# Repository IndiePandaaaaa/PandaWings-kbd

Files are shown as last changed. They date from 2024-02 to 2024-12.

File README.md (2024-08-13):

# PandaWings Keyboard

The PandaWings is a split keyboard with 3x5 column staggered keys with two 
additional keys on each side and with 3 thumb keys, based on 
[crkbd v3](https://github.com/foostan/crkbd/tree/v3-final).
Crkbd stands for Corne Keyboard.

## Idea

I wanted to create a corne compatible with the seeed xiao controller
instead of the pro-micro controllers. Due to missing pins for the matrix, 
the matrix is wired in a 4x5 grid and reshaped for thumb keys and two additional 
side keys. LEDs are permanent, toggleable with hardware switch. Per-key-RGB 
or display can be chosen while building.

## Lineup

- PandaWings v1 - Cherry MX switches: <br>
  Hotswappable Cherry MX switches, with LEDs, optional per-key-RGB or displays
- [PLANNED] PandaWings v2 - Cherry MX and Chocolate switches: <br>
  Hotswappable Cherry MX and Chocolate switches

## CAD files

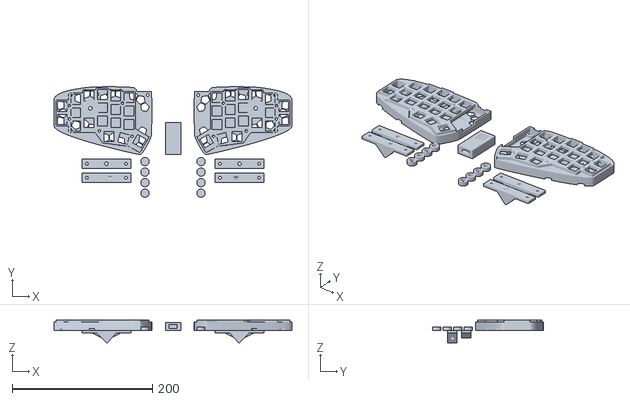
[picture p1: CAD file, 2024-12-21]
case/stl/PandaWings_case_full_set.stl
339.8 x 157.9 x 32.2

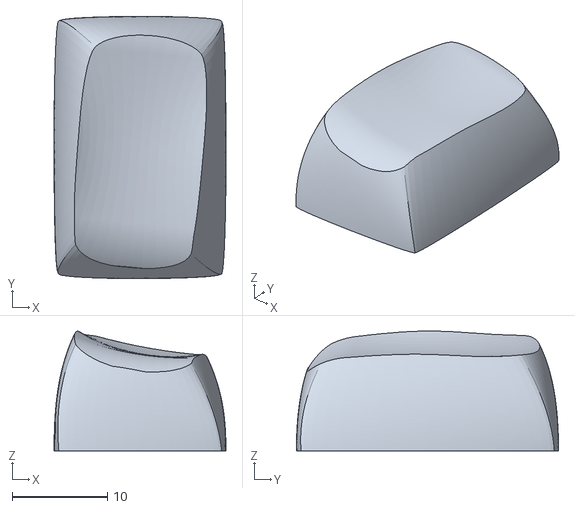
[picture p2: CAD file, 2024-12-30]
keycaps/stl/PandaWings-keycaps-thumbs-r1.stl
18.1 x 27.6 x 12.6

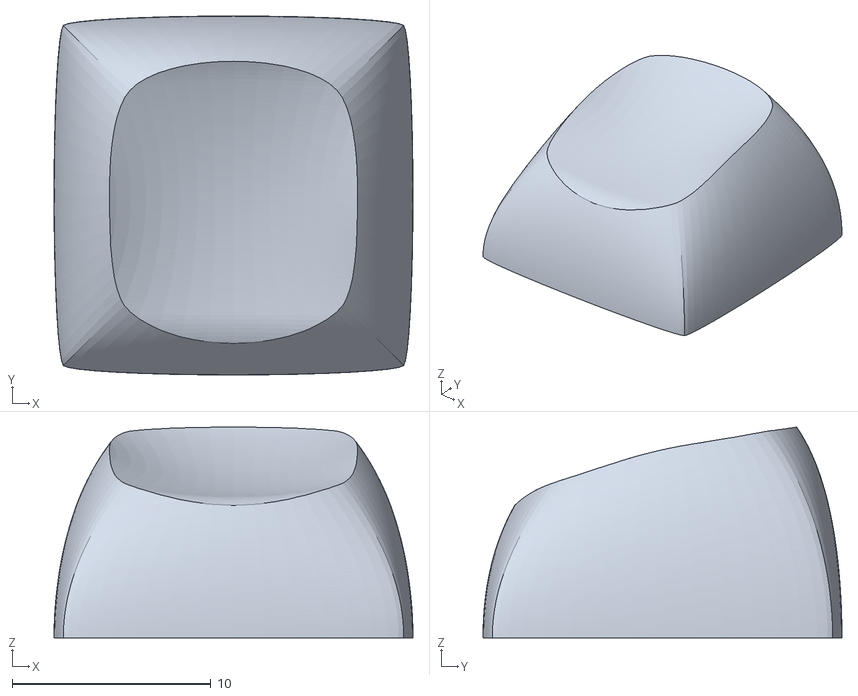
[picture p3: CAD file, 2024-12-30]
keycaps/stl/PandaWings-keycaps-alphanum-2-12x.stl
18.1 x 18.1 x 10.6

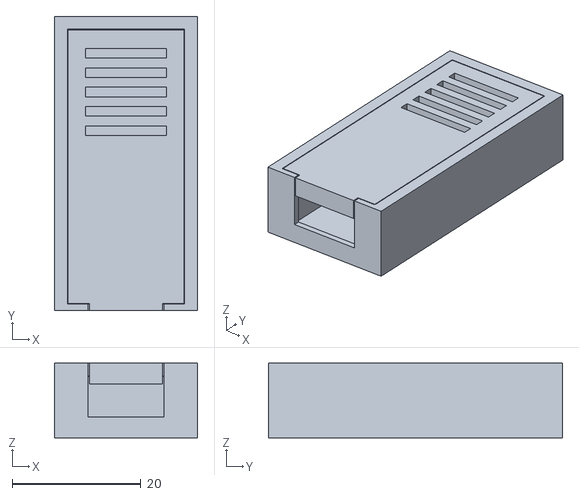
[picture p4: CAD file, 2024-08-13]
case/stl/PandaWings_dongle_case.stl
22.2 x 45.7 x 11.6

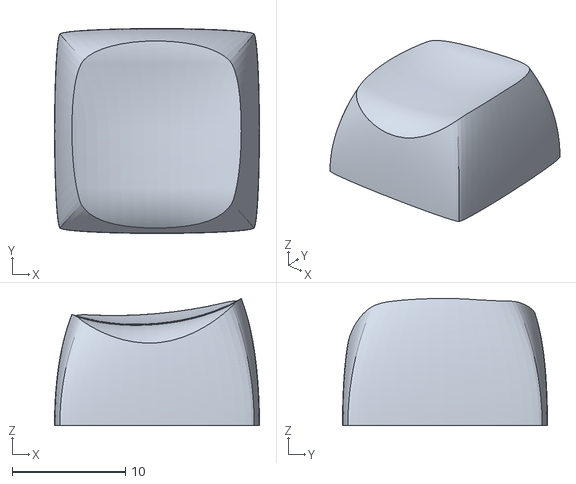
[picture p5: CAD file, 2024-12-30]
keycaps/stl/PandaWings-keycaps-thumbs-r2.stl
18.1 x 18.1 x 11.2

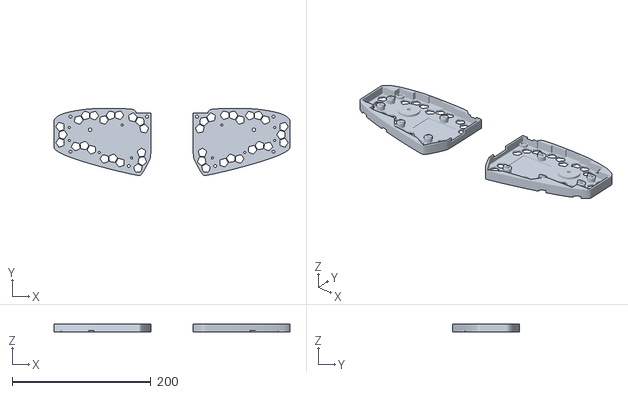
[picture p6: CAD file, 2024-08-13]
case/stl/PandaWings_case_M3.stl
339.8 x 96.8 x 11.9

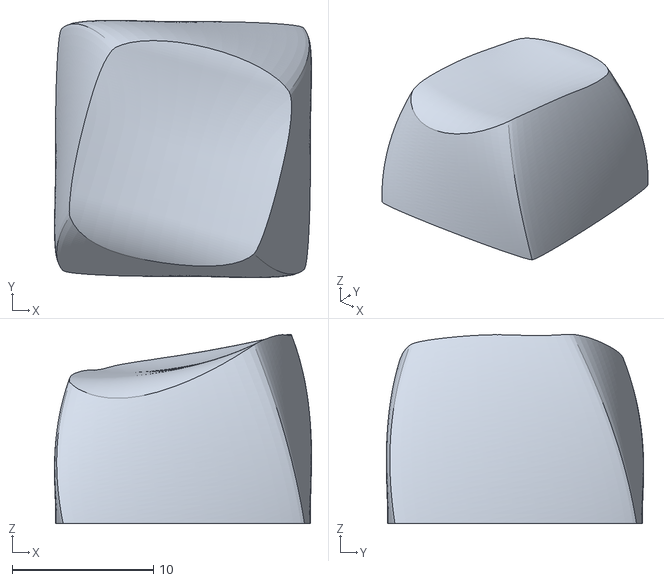
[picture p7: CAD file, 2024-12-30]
keycaps/stl/PandaWings-keycaps-thumbs-r3.stl
18.2 x 18.2 x 13.4

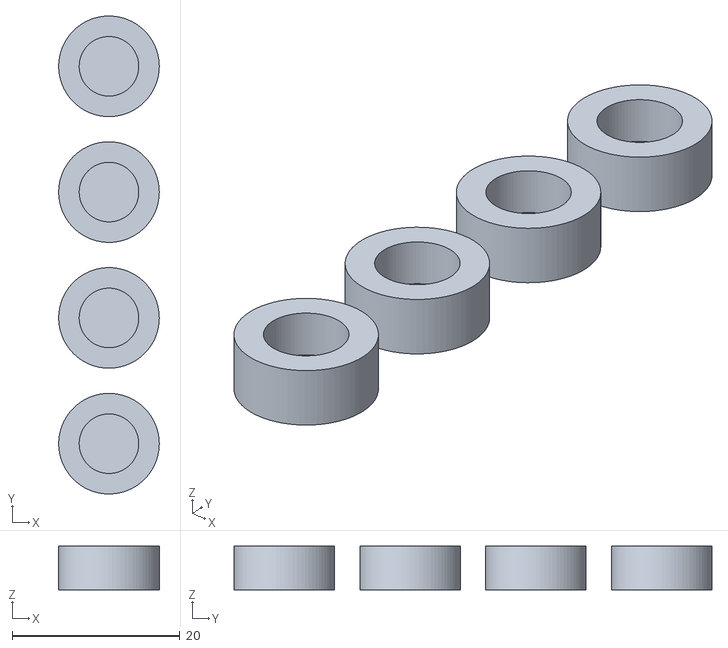
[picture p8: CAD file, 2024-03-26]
case/stl/PandaWings_tenting_caps_M4.stl
12.0 x 57.0 x 5.22

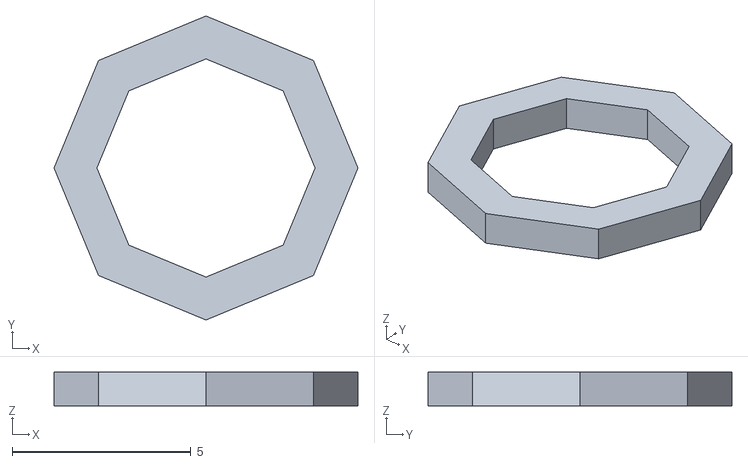
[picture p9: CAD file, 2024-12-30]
keycaps/stl/PandaWings-travelstop-gloriouspanda-gloriousa40thin.stl
8.50 x 8.50 x 0.95

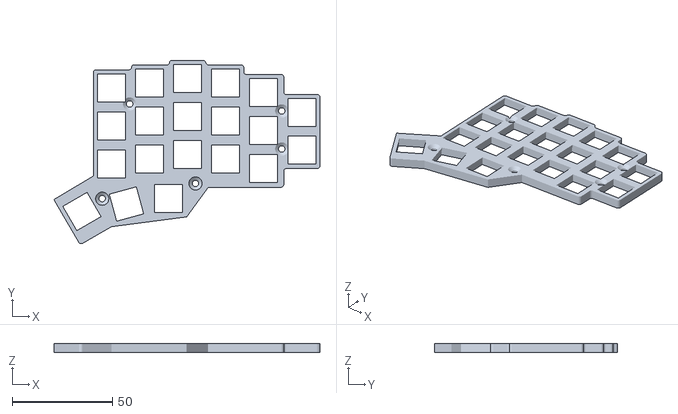
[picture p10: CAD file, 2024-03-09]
case/stl/PandaWings_switch_plate_M3.stl
132.9 x 91.6 x 4.70

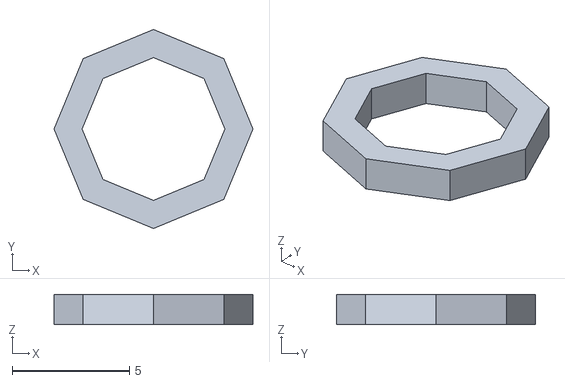
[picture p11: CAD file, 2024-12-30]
keycaps/stl/PandaWings-travelstop-cherrymxred-ring009.stl
8.50 x 8.50 x 1.30

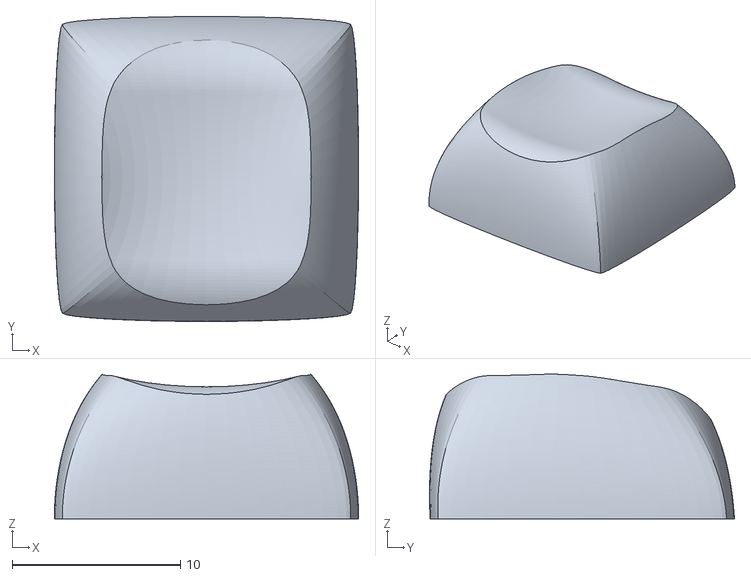
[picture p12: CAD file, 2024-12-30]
keycaps/stl/PandaWings-keycaps-alphanum-1-12x.stl
18.1 x 18.1 x 8.59

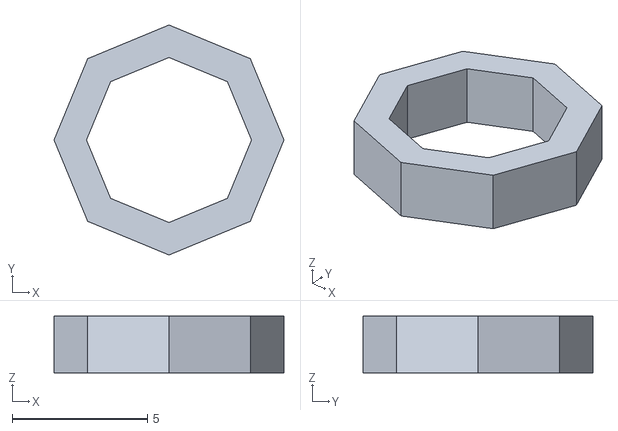
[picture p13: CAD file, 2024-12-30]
keycaps/stl/PandaWings-travelstop-cherrymxsilver-ring009.stl
8.50 x 8.50 x 2.10

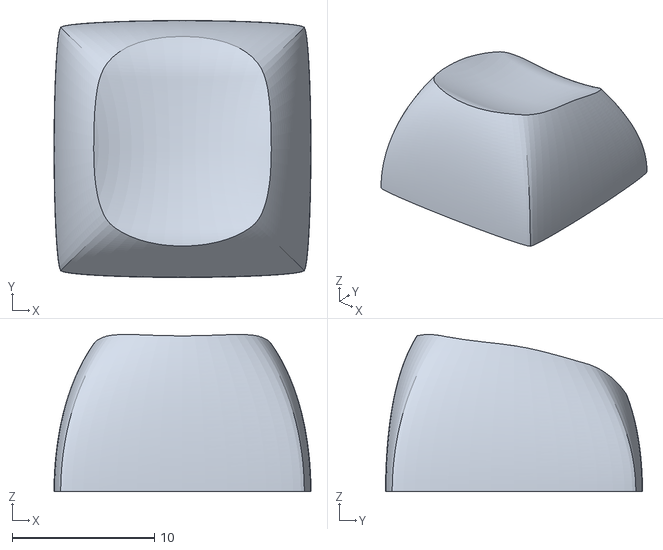
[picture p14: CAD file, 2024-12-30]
keycaps/stl/PandaWings-keycaps-alphanum-0-10x.stl
18.1 x 18.1 x 11.0

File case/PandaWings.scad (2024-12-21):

// created by IndiePandaaaaa

TOLERANCE = .15;
THICKNESS = 2.5;
$fn = 75;


// DONGLE
DONGLE_CASE = true;

// CASE
KEYBOARD_CASE = true;
SWITCH_PLATE = true;

// CASE ADDONS
WRIST_REST = false;
LAPTOP_STANDOFFS = false;
TENTING_CAPS = true;
TENTING_SOCKET = true;


BATTERY_SIZE = [41.2, 29.5, 4.8];  // Battery 600mAh (Jauch LP503040JH)

PCB_SIZE = [133.8, 92.6];

module nut_cutout(standard = "M3", thickness = 0, tolerance = .1) {

  nut_m3 = [6.1, 2.4];
  nut_m4 = [7.7, 3.2];
  
  rotate([0, 0, 30])
    if (standard == "M3" || standard == "m3" || standard == "3" || standard == 3)
      cylinder(d = nut_m3[0] + tolerance, h = nut_m3[1] > thickness ? nut_m3[1] + tolerance : thickness, $fn = 6);
    else if (standard == "M4" || standard == "m4" || standard == "4" || standard == "4")
      cylinder(d = nut_m4[0] + tolerance, h = nut_m4[1] > thickness ? nut_m4[1] + tolerance : thickness, $fn = 6);
}

module mounting(thickness, diameter = 4.7, screws = false, countersunk = false, nuts = false, standoffs = false) {
  cone_height_m3 = 1.7;
  cone_height_m4 = 2.3;
  
  standoff_offset = 2.75;

  MOUNTING_HOLES = [
    [18.9, 26.3],
    [18.9, 45.3],
    [62.0, 62.5],
    [94.9, 22.8],
    [108.6, 70.1],
  ];

  translate([PCB_SIZE[0], PCB_SIZE[1], 0]) mirror([0, 1, 0]) mirror([1, 0, 0]) union() {
    for (i = MOUNTING_HOLES) {
      translate([i[0], i[1], 0]) {
        if (countersunk && !nuts && diameter >= 3 && diameter <= 3.5)
          translate([0, 0, thickness - cone_height_m3 - .5])
            cylinder(d1 = diameter, d2 = diameter * 2 + 0.4, h = cone_height_m3 + .5);
        else if (countersunk && !nuts && diameter >= 4 && diameter <= 4.5)
          translate([0, 0, thickness - cone_height_m4 - .5])
            cylinder(d1 = diameter, d2 = diameter * 2 + 0.4, h = cone_height_m4 + .5); 
        else if (!countersunk && nuts && diameter == 3)
          nut_cutout("M3", thickness);
        else if (!countersunk && nuts && diameter == 4)
          nut_cutout("M4", thickness);
      }

      if (screws && !nuts) translate([i[0], i[1], 0]) cylinder(d = diameter, h = thickness);

      if (standoffs) translate([i[0] + standoff_offset, i[1], 0]) cylinder(d = diameter, h = thickness);
    }
  }
}

module dongle_case(thickness = 2, tolerance = .2) {
  adapter_width = 14.5; // Adafruit P5329
  adapter_length = 14.5;
  adapter_height = 7.2;
  
  controller_width = 17.8; // Seeed XIAO BLE
  controller_length = 21.0;

  connector_wall_thickness = 1;
  connector_offset = 1.2;
  connector_width = 11.4;
 
  distance_length = 4.4;
  distance_width = 10;

  top_tolerance = .1;

  total_length = connector_wall_thickness + adapter_length + distance_length + controller_length + thickness * 2 + tolerance * 4;
  total_width = (thickness + tolerance) * 2 + controller_width;
  total_height = (thickness + tolerance) * 2 + adapter_height;

  inner_height = total_height - thickness - top_tolerance;
  connector_wall_width = (total_width - connector_width) / 2 - tolerance;
  adapter_wall_width = (total_width - adapter_width) / 2 - tolerance;
  
  union() {
    // bottom
    cube([total_width, total_length, thickness]);
    cube([total_width, connector_wall_thickness, thickness + connector_offset]); 
    translate([0, total_length - controller_length, 0]) cube([total_width, controller_width, thickness + connector_offset]);

    // walls
    cube([thickness, total_length, total_height]);
    translate([total_width - thickness, 0, 0]) cube([thickness, total_length, total_height]);
    translate([0, total_length - thickness, 0]) cube([total_width, thickness, total_height]);
    translate([0, total_length - thickness * 2, 0]) cube([total_width, thickness, inner_height]);
    cube([adapter_wall_width, connector_wall_thickness + adapter_length, inner_height]);
    translate([total_width - adapter_wall_width, 0, 0])
      cube([adapter_wall_width, connector_wall_thickness + adapter_length, inner_height]); 
    cube([connector_wall_width, connector_wall_thickness, total_height]);
    translate([total_width - connector_wall_width, 0, 0])
      cube([adapter_wall_width, connector_wall_thickness, total_height]);
  }

  difference() {
    union() {
      top_length = total_length - thickness - connector_wall_thickness - top_tolerance * 2;
      translate([thickness + top_tolerance, connector_wall_thickness + top_tolerance, total_height - thickness])
        cube([controller_width + (tolerance - top_tolerance) * 2, top_length, thickness]);
      translate([connector_wall_width + tolerance, 0, total_height - thickness - connector_offset]) {
        cube([connector_width, connector_wall_thickness, thickness + connector_offset]);
        translate([0, 0, connector_offset]) cube([connector_width, thickness, thickness]);
      }
    }

    cooling_width = 12.5;
    cooling_y = 27.2;
    for (i = [0:4]) {
      translate([(total_width - cooling_width) / 2, cooling_y + 3 * i, total_height - thickness - tolerance])
        cube([cooling_width, 1.5, thickness + tolerance * 2]);
    }
  }
}

module switch_plate(thickness = 2.5) {
  max_thickness = 4.7;
  mx_plate_thickness = 1.5;

  translate([3, 3.2, 10]) difference() {
    linear_extrude(max_thickness)
      import("./svg/PandaWings_contour_half_switch_plate.svg", dpi = 300);
    translate([0, 0, -.1]) linear_extrude(max_thickness - mx_plate_thickness + .1)
      import("./svg/PandaWings_contour_half_switch_plate_outer_cutout.svg", dpi = 300);
    translate([0, 0, max_thickness - mx_plate_thickness - .1]) linear_extrude(mx_plate_thickness + .2)
      import("./svg/PandaWings_contour_half_switch_plate_inner_cutout.svg", dpi = 300);
    translate([0, 0, -.1]) mounting(max_thickness + .2, 3.2, screws = true, countersunk = true); // 3.2 mm for M3
  }
}

module wrist_rest_mounting(thickness, case_height, cutout = false) {
  translate([82, 10, 0]) {
    wr_loc = [ [0, 0], [40, 9.5] ];
    size = [9, 20, thickness + .2];

    for (i = wr_loc) {
      translate([i[0], i[1], -.1]) union () {
        cube([size[0], size[1] - size[0] / 2, size[2]]);
        translate([size[0] / 2, size[1] - size[0] / 2, 0]) {
          cylinder(d = size[0], h = size[2]);
          cylinder(d = 2.95, h = case_height - 1.5);
        }
      }
    }
  }
}

module keyboard_case(wrist_rest = true, thickness = 2.5, min_thickness = 1.5, pcb_thickness = 1.6) {
  // heights
  battery_connector_height = 5;
  above_pcb = 3;
  below_pcb = min_thickness + BATTERY_SIZE[2] + 1;
  case_height = below_pcb + pcb_thickness + above_pcb;

  mounting_offset = [2.95, 3.2];
  // todo: find height issue, below_pcb != underside of pcb
  
  tenting_locations = [
    [6, 85], 
    [32, 14],
    [116.25, 34.5],
    [116.25, 85],
  ];

  tenting_socket_pos = [88, 66, 5.2];

  difference() {
    union() {
      difference() {
        linear_extrude(case_height)
          import("./svg/PandaWings_contour_case.svg", dpi = 300); 
        translate([0, 0, thickness]) linear_extrude(case_height - thickness + .1)
          import("./svg/PandaWings_contour_half_pcb.svg", dpi = 300);
        translate([0, 0, -.1]) linear_extrude(thickness + .2)
          import("./svg/PandaWings_contour_case_cutout.svg", dpi = 300);
        translate([mounting_offset[0], mounting_offset[1], -.1]) mounting(thickness + .2, 3, nuts = true);
      }
      translate([tenting_socket_pos[0], tenting_socket_pos[1], 0]) cylinder(d = 26, h = tenting_socket_pos[2]);
      difference() {
        translate([mounting_offset[0], mounting_offset[1], thickness]) union() {
          mounting(below_pcb, 4.5, screws = true);
          mounting(below_pcb - 2, 10, screws = true);
        }
      }


      translate([mounting_offset[0], mounting_offset[1], thickness]) 
        mounting(below_pcb, diameter = 4.5, standoffs = true);
      
      for (i = tenting_locations) {
        translate([i[0], i[1], thickness -.1]) {
          difference() {
            cylinder(d = 10, h = 3);
            nut_cutout("M4", 3);
          } 
        }
      }
    }

    for (i = tenting_locations) translate([i[0], i[1], -.1]) cylinder(d = 4.2, h = below_pcb + .1);
    translate([mounting_offset[0], mounting_offset[1], thickness - .1]) 
      mounting(below_pcb + .2, 3.2, screws = true);

    // battery
    translate([20, 38, min_thickness + .15]) cube(BATTERY_SIZE);

    // USB port
    translate([7.5, 88, below_pcb + 2.5]) cube([9, 5, 8]);

    // side switches
    translate([0, 34, below_pcb]) cube([5, 24, 55]);

    // wrist rest mounting
    wrist_rest_mounting(thickness, case_height, cutout = false);

    // tenting socket
    translate([tenting_socket_pos[0], tenting_socket_pos[1], -.1]) cylinder(d = 5.1, h = tenting_socket_pos[2] + .2); // UNC 1/4" threading
  }

}
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

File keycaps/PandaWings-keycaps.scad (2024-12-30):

// created by IndiePandaaaaa

use <des/MX_DES_Thumb.scad>
use <des/MX_DES_Standard.scad>
use <des/MX_DES_travel_stop.scad>

RENDER_ALL_CAPS = false;

// cherry activation point
CSILVER = 1.2;  // cherry mx silver
CRED = 2;  // cherry mx red
GPANDA = 2.5;  // glorious panda

// o-ring uncompressed thickness
RING_009 = 1.8;
GLORIOUS_A40_THIN = 1.5;

// needed keys
standard = [ [0, 10], [1, 12], [2, 12] ];
thumbs = [ [0, 1], [1, 1], [2, 1] ];
keycount = 6 + standard[0][1] + standard[1][1] + standard[2][1];


module standard_caps(id) {
  keycap_standard(
    keyID = id, // change profile refer to KeyParameters Struct
    cutLen = 0, // Don't change. for chopped caps
    Stem = true, // turn on shell and stems
    Dish = true, // turn on dish cut
    Stab = 0,
    visualizeDish = false, // turn on debug visual of Dish
    crossSection = false, // center cut to check internal
    homeDot = false, // turn on homedots
    Legends = false  // not working
  );
}

module thumb_caps(id) {
  keycap_thumb(
    keyID = id, //change profile refer to KeyParameters Struct
    cutLen = 0, //Don't change. for chopped caps
    Stem = true, //tusn on shell and stems
    Dish = true, //turn on dish cut
    Stab = 0,
    visualizeDish = false, // turn on debug visual of Dish
    crossSection = false, // center cut to check internal
    homeDot = false, //turn on homedots
    Legends = false // not working
  );
}

union() {
  // alphanumerical keycaps
  translate([10, 30, 0]) for (i = [0:len(standard) - 1]) {
    for (j = [0:(RENDER_ALL_CAPS ? standard[i][1]:0)]) {
      translate([RENDER_ALL_CAPS ? 20 * j - (20 * standard[i][1]) / 2 : 0, 20 * i, 0]) standard_caps(id = standard[i][0]);
    }
  }
  
  // thumb cluster keycaps
  translate([10, 0, 0]) for (i = [0:1]) {
    mirror([i, 0, 0]) translate([20 * i, 0, 0]) for (x = [0:len(thumbs) - 1]) {
      translate([20 * x, 0, 0]) thumb_caps(id = thumbs[x][0]);
    }
  }

  // travel_stop
  translate([10, -30, 0]) for (i=[0: (RENDER_ALL_CAPS? keycount-1:0)]) {
    translate([15*(i%5), -15*floor(i/5), 0]) travel_stop(GPANDA, GLORIOUS_A40_THIN);
  }
}

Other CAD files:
keycaps/stl/PandaWings-keycaps-thumbs-l2.stl
keycaps/stl/PandaWings-keycaps-thumbs-l1.stl
keycaps/stl/PandaWings-keycaps-thumbs-l3.stl
case/stl/PandaWings_tenting_mounting_wood_screws.stl

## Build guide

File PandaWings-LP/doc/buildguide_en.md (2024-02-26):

# Build Guide

This is the build guide for Corne Chocolate.
[Click here for the Corne Cherry build guide](
https://github.com/foostan/crkbd/blob/master/corne-cherry/doc/buildguide_en.md).

## Parts

### Required

| Name | Count | Remarks |
|:-|:-|:-|
| PCB | 2 pieces | |
| Top plate | 2 pieces | |
| Bottom plate | Two pieces | PCB type and acrylic type are available |
| Pro Micro protection plate | 2 pieces | |
| Pro Micro | 2 | |
| TRRS Jack | 2 | |
| Tactile switch | 2 pieces | |
| Diode | 42 pieces | Compatible with chip components only
| Kailh PCB Socket (for Choc) | 42 | |
| Key switch | 42 pieces | Compatible with Choc (low profile) only |
| Key-caps | 42 | 1u 40, 1.5u 2 |
| OLED module | 2 pieces | |
| 4 pin headers | 2 | |
| 4 pin sockets | 2 | |
| Spacer M2 4.5mm | 10 | |
| Spacer M2 9mm | Four | |
| Screw M2 4mm | 28 | |
| Cushion rubber | 8 pieces | |
| TRS (3 pole) cable | 1 | TRRS (4 pole) cable also available |
| Micro USB Cable | 1 | |

### Optional

| Name | Count | Remarks |
|:-|:-|:-|
| SK6812MINI | 54 | 42 for backlight, 12 for under-glow |

## Advance preparation

If you build the firmware yourself,
it will take some time to set up the environment,
so it's best to start at the beginning. \
For more information,
please see <https://github.com/foostan/crkbd/blob/master/doc/firmware_en.md>.

## Building

Since the PCB is reversible,
you first have to decide which one to use for the left side.



### Diodes

Solder the diodes to the PCB.

On Corne Cherry, it is up to you to choose which side to attach,
but with Corne Chocolate you must **be sure to attach it to the back**.
Mounting on the front will interfere with the top plate.

Since the diodes are very small,
it is easier to work with tweezers and inverted tweezers.
Since the **mounting orientation of the diode is crucial**,
it is possible to proceed smoothly
if you arrange the columns and rows to be mounted in advance,
as shown in the following photo.



The orientation of the diode is as follows.
Attach the chip component so that the "|||" mark on the diode is facing the "|"
of the diode mark "|◁" on the PCB (image from Corne Cherry).



Tip for soldering on SMD parts:
First put solder only on the right side of the pad.



Next, solder one of the diodes by melting the solder you already put on the board.
At this time,
it is recommended to use [reverse-action tweezers](https://www.alimed.com/_resources/cache/images/product/70895A_850x480-pad.jpg),
so that you can hold the SMD part firmly without applying force,
and concentrate on alignment and soldering instead.
Also, if the soldering iron is too hot or the solder is touched too long,
the flux contained in the solder may evaporate and form an undesirable pile solder,
but since it can be repaired later,
so at this point you should only care about attaching parts.
It's okay.



Then solder the other pin.
Be careful not to apply too much solder,
as a small amount is sufficient.
If you have applied too much,
you can remove it with a suction pump, blotting wire
or by scooping it with a soldering iron.



If the amount of solder on the pre-soldering side is too small,
add more soldering,
and if it is pilled up,
apply flux from above and heat to clean.



### TRRS jack, reset switch, pin socket



Solder the TRRS jack, reset switch and pin socket to the **front of the PCB**
as shown in the picture below.
Since the diode is attached on the back side,
it will be on the opposite side.



### Jumpers for OLED modules

When using an OLED module, use solder as jumpers (4 times per side) as follows.
**Please jumper only on the surface**.



If the jumper doesn't work,
you probably have a small amount of solder,
or the flux has vaporized.
If so, you can fix the jumper by applying more solder or separate flux.

### Pro Micro



Solder the pin headers to the white frame
and solder the Pro Micro with back side up.




When using the spring-loaded pin headers,
please refer to the [Helix Build Guide](
https://github.com/MakotoKurauchi/helix/blob/master/Doc/buildguide_en.md#pro-micro).

### OLED module



Insert the pin header into the OLED pin socket first,
then solder the pin header and the OLED module.
At this time,
make sure that the OLED module sits tightly on the socket
while holding it down with your finger,
because it tends to stick out easily.




### Operation check

We recommend that you check the operation at the stage
where the Pro Micro and OLED modules are attached
(it is difficult to isolate the problem at the end).

Before checking the correct operation,
flash the crkbd firmware to the Pro Micro
by referring to the [Firmware](#firmware) section below
(be sure to insert it on both sides).

Operation confirmation is performed
by connecting the left hand side to a PC with Micro USB
and connecting the left hand side and the right hand side with a TRS cable.
Since there may be a defect such as a jack,
make sure to connect the left and right
instead of one by one before checking the operation.
If you have done this correctly,
short-circuit the pad to attach the PCB socket with tweezers,
and the key pressed on the OLED module will be displayed.



## LED (optional)



I will install SK6812MINI.
The LED can be mounted even after completion,
so if you are worried about mounting it,
we recommend that you skip this chapter and complete it first.

SK6812MINI is very heat sensitive and breaks easily.
We recommend using a soldering iron with a temperature control function
and operating at a temperature of about 220°C to 270°C.
Even if the temperature is set that low,
the LED will be damaged if the iron is left on it for a long time,
so try to solder as quickly as possible.
Solder four LEDs at a time,
but we recommend soldering two at a time instead of four at a time
to prevent the LED temperature from rising,
as this will make it less likely to overheat.

First, check the mounting position.

Solder 1 - 6 so that the back side (under-glow) shines,
7 - 27 so that the front side (back-light) shines.
Below is the location to attach the LED (image from Corne Cherry).




For LEDs 1 to 6,
solder the part so that the black part circled below is on the bottom
and the silk mark indicated by the arrow is on the top.
Note that the direction changes between 1 - 3 and 4 - 5.



For 7 - 27,
perform soldering so that the largest pad surrounded by a circle
and the silk mark indicated by an arrow are adjacent to each other,
as shown below.



If everything was successfully soldered,
it will glow as follows.
If the LED lights only halfway,
the LEDs are connected in the order of the numbers.
Therefore, it is likely that the LED that does not emit light
or the previous LED are incorrectly soldered or damaged.





### Kailh PCB Socket



Apply solder to the pads on both sides on the back.
It is difficult to add it later,
so please fill it up beforehand.



Insert the socket and melt the solder.
At this time,
hold the socket with tweezers or your fingers so that the socket sticks to the board.



The soldering is now complete.




### Plate, switch



Use 4.5mm spacers for the top and bottom plates
and 9mm spacers for the OLED.



In addition,
it is recommended to paint the side of the plate with a black marker
because it looks better.



## Firmware

See below to flash the firmware to the ProMicro. \
<https://github.com/foostan/crkbd/blob/master/doc/firmware_en.md>

This is the end.



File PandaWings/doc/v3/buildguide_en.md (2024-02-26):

# Build Guide

This is the build guide for Corne Cherry v3.
[Click here for the Corne Cherry v2 build guide](
https://github.com/foostan/crkbd/blob/master/corne-cherry/doc/v2/buildguide_en.md).

## Parts

### Required

| Name | Count | Remarks |
|:-|:-|:-|
| PCB | 1 set | |
| Top plate | 2 sheets | 1.5mm-3mm thick |
| Bottom plate | 2 sheets | |
| OLED cover | 2 sheets | |
| ProMicro | 2 | Alternative: [Elite-C](https://deskthority.net/wiki/Elite-C) |
| TRRS jack | 2 | |
| Reset switch | 2 | |
| Diodes | 42 | SMD Only (SOD-123 Package) |
| PCB sockets | 42 | Compatible with Kailh and Gateron |
| Key switches | 42 | Only compatible with MX style |
| Keycaps | 42 pieces | 1u 40 pcs, 1.5u 2 pcs |
| Spacer M2 7.5mm | 10 pieces | For Case assembly |
| Spacer M2 9mm | 4 pieces | For OLED cover |
| Screw M2 4mm | 28 screws | |
| Rubber feet | 8 pieces | |
| TRRS (4 poles) cable | 1 | TRS (3 poles) cable is also compatible |
| Micro USB cable | 1 | Avoid charge-only cables |

### Optional

| Name | Count | Remarks |
|:-|:-|:-|
| OLED module | 2 | |
| SK6812MINI-E | 42 | LEDs for Backlight |
| WS2812B | 12 | LEDs for Undergrow |
| [Microcontroller/OLED Sockets](https://www.digikey.com/en/products/detail/315-43-112-41-003000/ED4764-12-ND/4455232) | 1 | Alternative: [2.54 1row femal sliv](https://www.aliexpress.com/item/4001122376295.html) option |
| [Microcontroller Pins](https://www.digikey.com/en/products/detail/mill-max-manufacturing-corp/3320-0-00-15-00-00-03-0/4147392) | 48 | Alternative: Diode/Resistor legs |
| [OLED Headers](https://www.digikey.com/en/products/detail/mill-max-manufacturing-corp/350-10-164-00-006000/357045) | 1 | Soldered to OLED module |

## Firmware preparation

If you build the firmware yourself, it will take some time to set up the environment,
so it's best to start at the beginning.\
It is recommended to flash ProMicro's prior to soldering.\
For more information,
please see <https://github.com/foostan/crkbd/blob/master/doc/firmware_en.md>.

## Verification

The PCB for Corne Cherry v3 is as follows.
Make sure it is the same as your PCB.

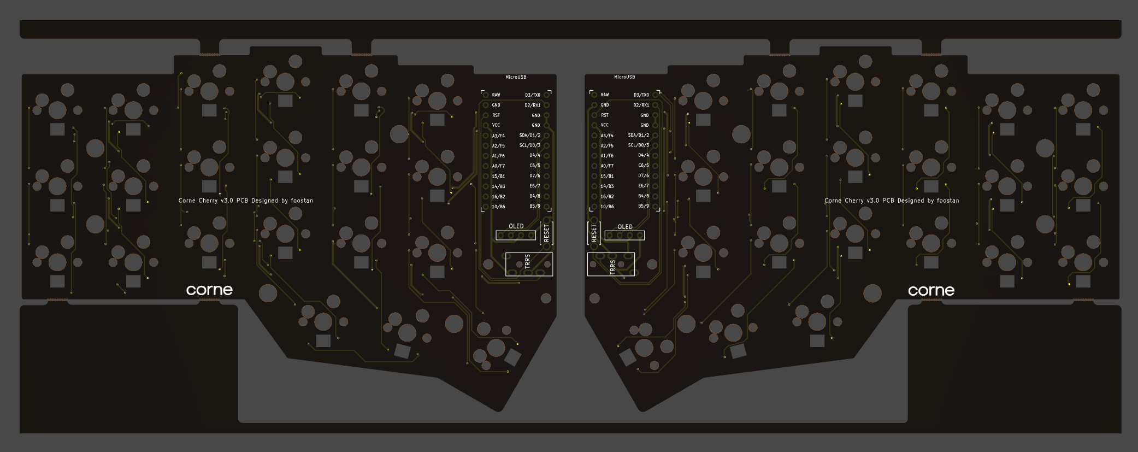
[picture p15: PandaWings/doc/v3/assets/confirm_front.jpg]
confirm_front


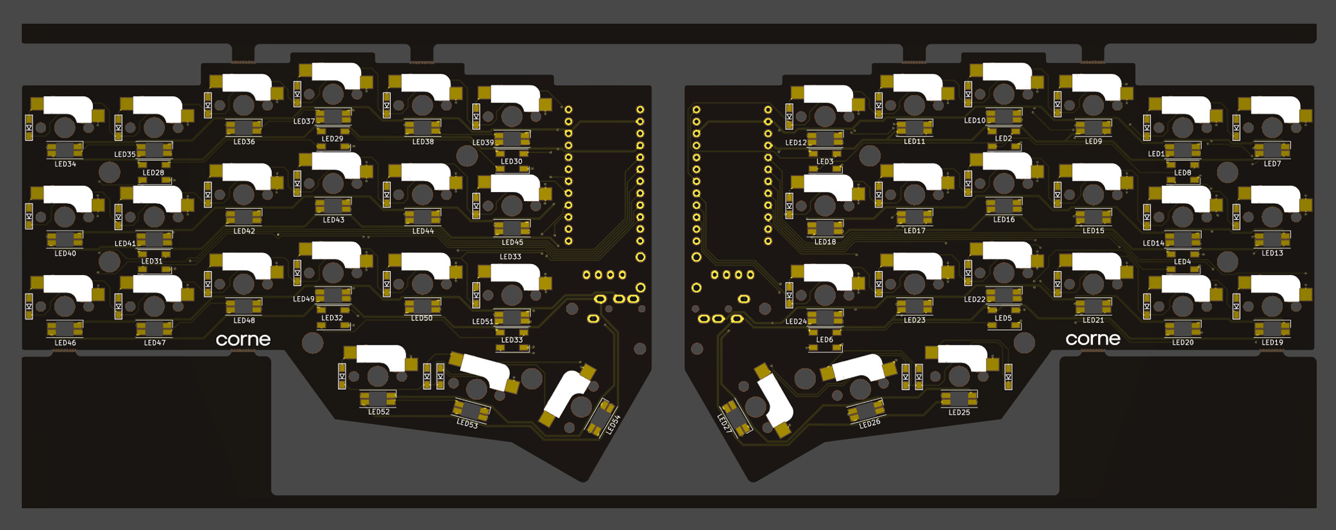
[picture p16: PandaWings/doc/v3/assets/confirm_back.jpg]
confirm_back


The PCB comes with a frame for manufacturing reasons.
You can fold it by hand to remove it, but if it is difficult,
make a cut in the joint\* with a cutter or similar,
to make it easier to remove.
In addition, the joint can be cleaned with a file.

\**Joint part: There are a total of 8 parts,
which are marked in red in the image below.*

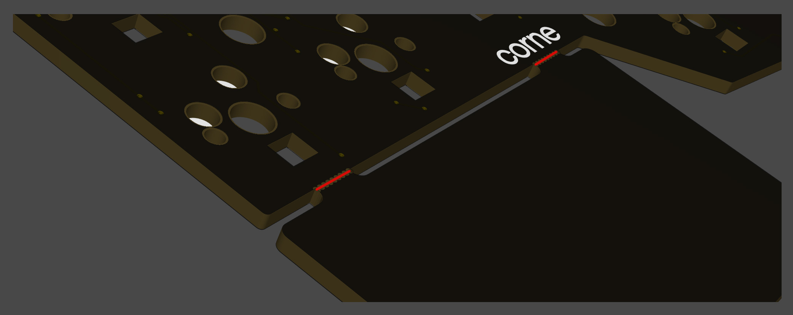
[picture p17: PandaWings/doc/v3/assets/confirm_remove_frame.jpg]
confirm_remove_frame


## Assembly

### Diodes

Since SMD parts are very small, fine-tip/reverse-action tweezers are recommended.

**The diodes have a specific orientation**, so install with "|" marking on the diode
facing the "|" on the PCB marking: "|◁"

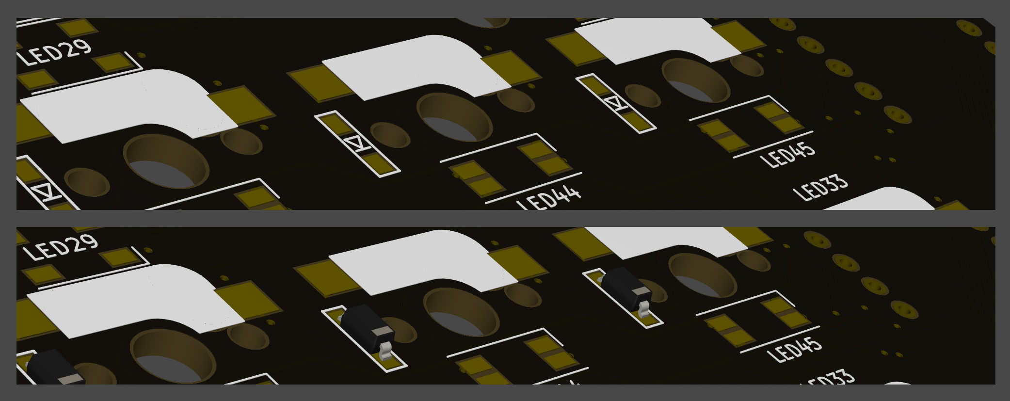
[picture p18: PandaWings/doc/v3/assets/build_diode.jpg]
build_diode


<details>
<summary>TIPS: Tips for installing SMD parts</summary>

Begin with applying solder to only one pad.

tips_building_smd_01

Next, place SMD component while heating solder. At this time,
it is recommended to use [reverse-action tweezers](https://www.alimed.com/_resources/cache/images/product/70895A_850x480-pad.jpg),
so that you can hold the SMD part firmly without applying force,
and concentrate on alignment and soldering instead.
Also, if the soldering iron is too hot or the solder is touched too long,
the flux contained in the solder may evaporate and form a poor solder joint,
but it can be repaired later,
so at this point you should only care about attaching parts.
It's okay.

tips_building_smd_02

It is okay if the SMD component is not flush with the PCB when viewed from the side.
If it is floating, press the SMD component down with tweezers or your finger and reheat the solder.

tips_building_smd_03

Then solder the other contacts.
Be careful not to apply too much solder,
as a small amount is sufficient.
If you have applied too much,
you can remove it with a suction pump, solder wick,
or by picking it up with a soldering iron.

If the amount of solder on the preliminary solder side is small,
additional soldering is performed, and if it is a heap,
apply flux from above and heat it to clean it.

tips_building_smd_04

</details>

The diode is completed by soldering 42 pieces in total on the left and right.

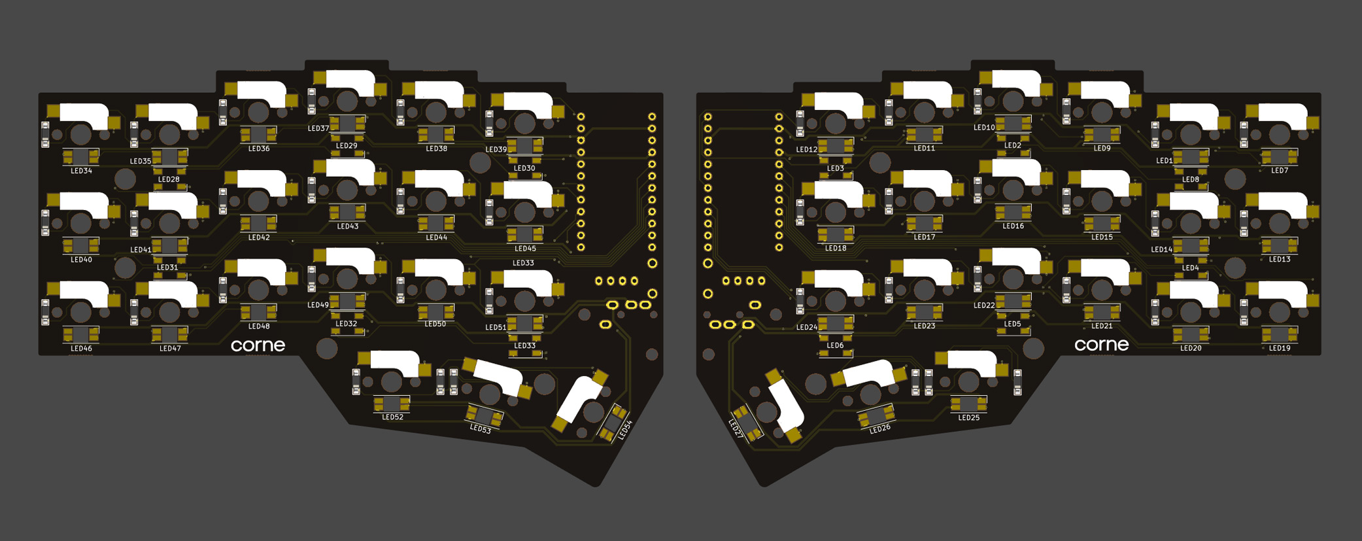
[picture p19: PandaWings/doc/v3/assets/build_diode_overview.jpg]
build_diode_overview


### LED (optional)

Solder the SK6812MINI-E and WS2812B.

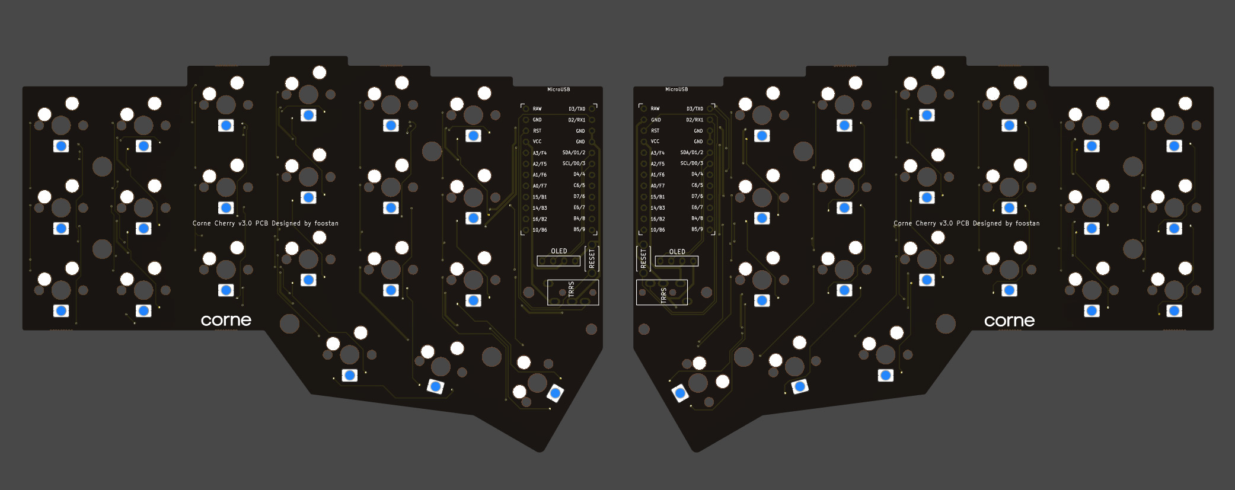
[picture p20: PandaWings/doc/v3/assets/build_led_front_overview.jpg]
build_led_front_overview


All soldering is done from the back side, but the SK6812MINI-E is for Backlight
(the front side is shining) and the WS2812B is for Undergrow (the back side is shining).

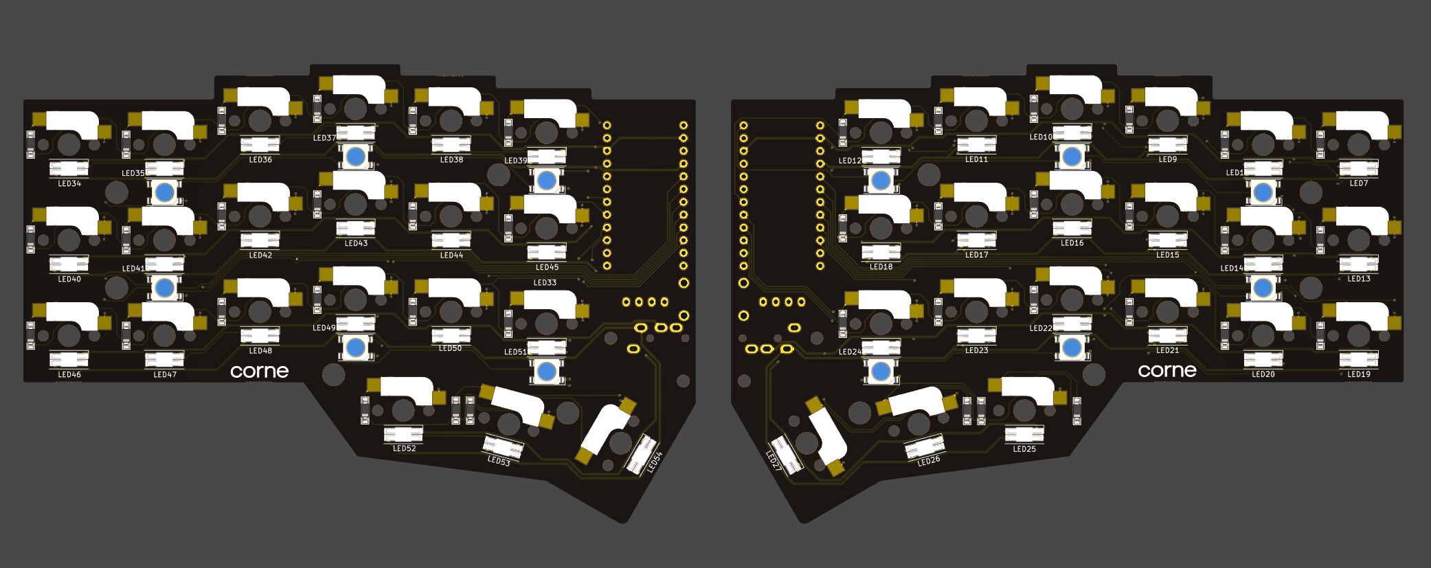
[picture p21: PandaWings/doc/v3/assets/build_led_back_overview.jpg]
build_led_back_overview


#### WS2812B (Undergrow)

First, solder the WS2812B.

Match recessed corner of the LED with marked corner on the PCB as shown below.
Refer to **TIPS: Tips for installing SMD parts** section above as similar soldering
procedure is followed. 

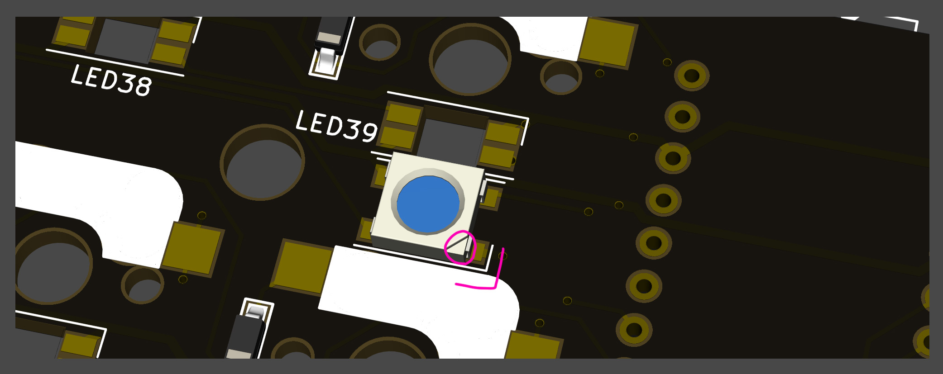
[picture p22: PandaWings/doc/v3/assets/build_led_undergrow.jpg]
build_led_undergrow


WS2812B LED soldering is completed after 12 are installed on left and right.

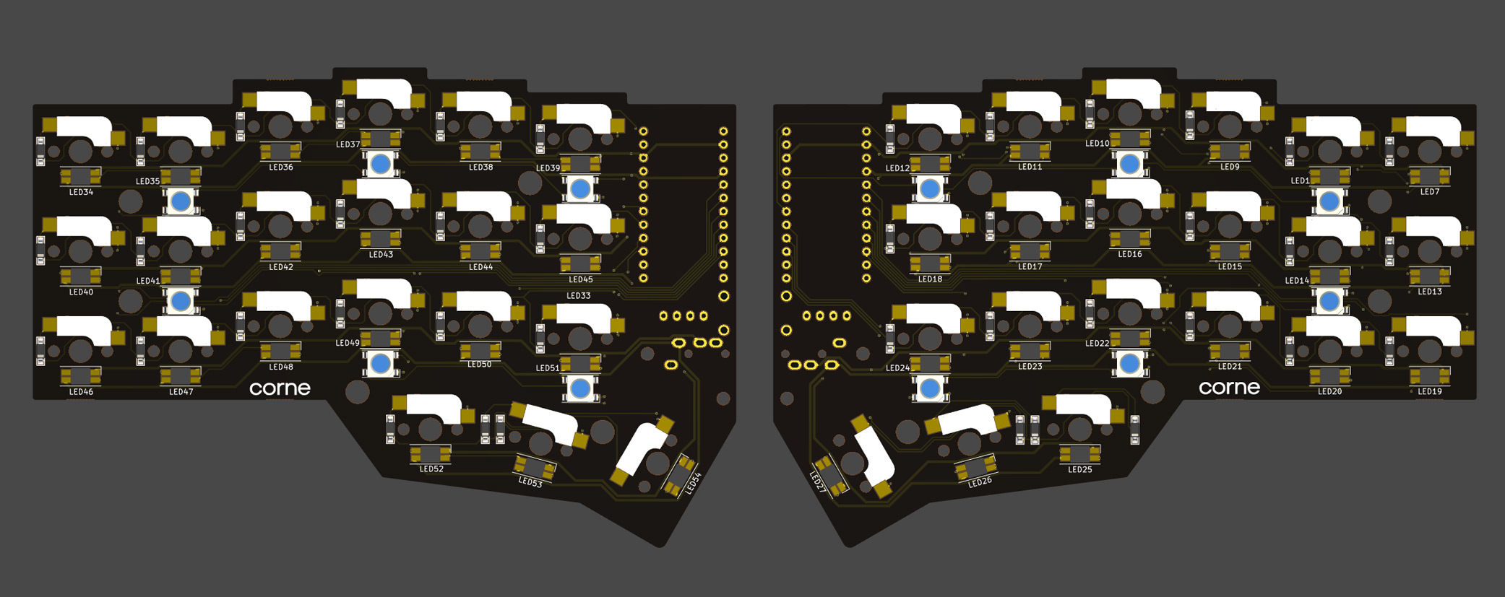
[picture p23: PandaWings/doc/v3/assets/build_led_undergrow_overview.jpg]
build_led_undergrow_overview


#### SK6812MINI-E (Backlight)

Then solder the SK6812MINI-E.

Match the notched corner of the LED with the marked corner on the PCB as show below.
Refer to **TIPS: Tips for installing SMD parts** section above as similar soldering
procedure is followed. 
These are more resilient than the SK6812MINI LEDs,
but still may be damaged if directly exposed to the heat of a soldering iron.
~320°C seems to be an ok temperature, evne if all four legs are soldered 
one after another.

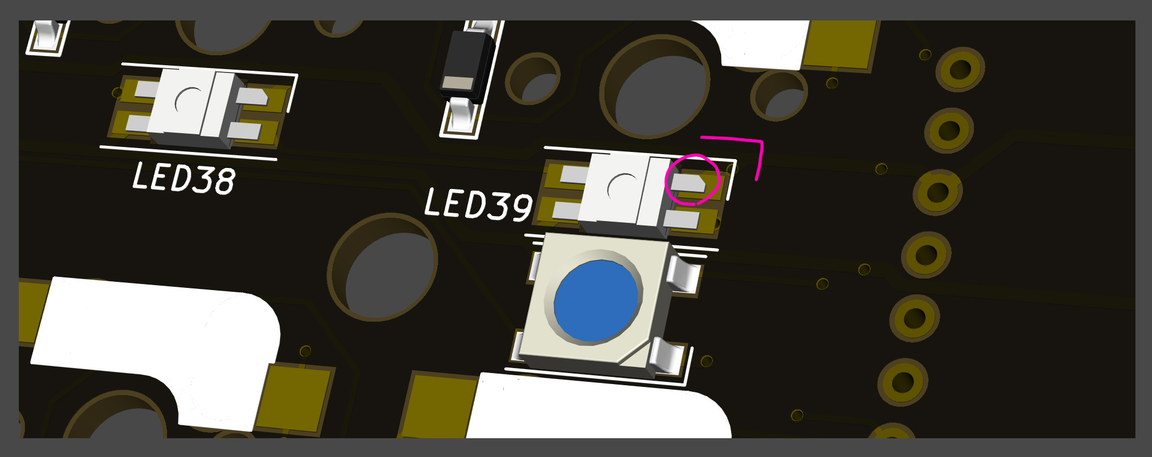
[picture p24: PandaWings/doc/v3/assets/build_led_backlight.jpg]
build_led_backlight


SK6812MINI-E LED soldering is completed after 42 are installed on left and right.

build_led_back_overview

### TRRS jack, reset switch, pin socket for OLED

Solder the TRRS jack, reset switch (tact switch),
and OLED pin socket as shown in the picture below.

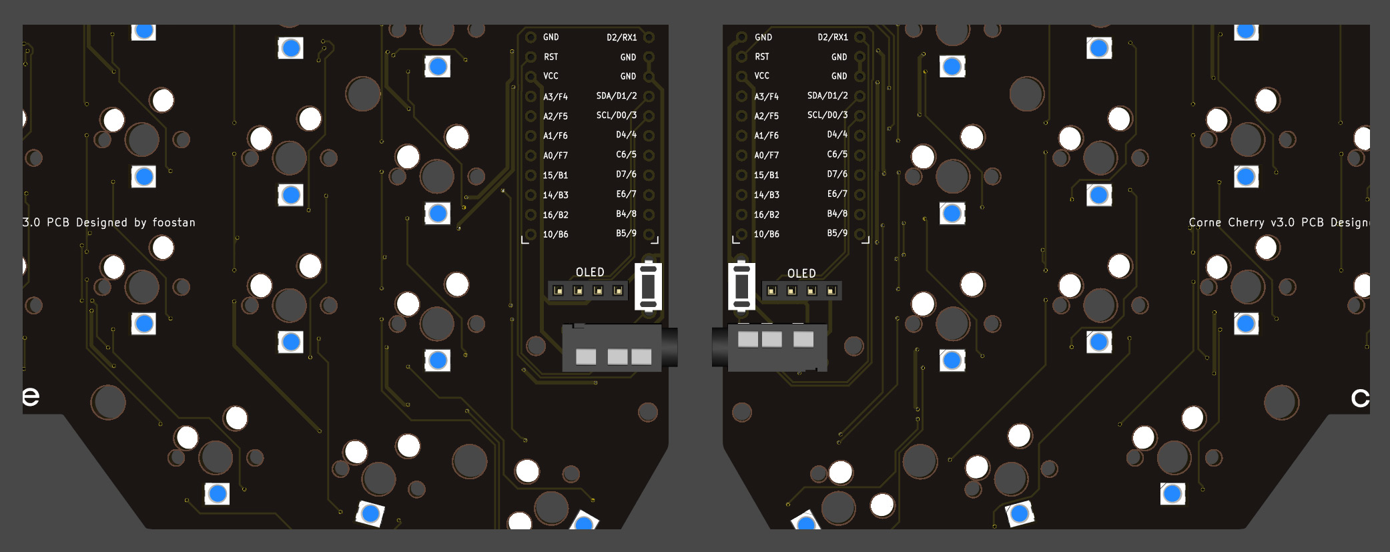
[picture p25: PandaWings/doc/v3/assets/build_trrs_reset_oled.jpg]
build_trrs_reset_oled


Since these parts may fall off when soldering, you can affix them with masking tape.

### ProMicro

Solder headers to PCB. Then solder ProMicro to headers, with components facing PCB as shown below.

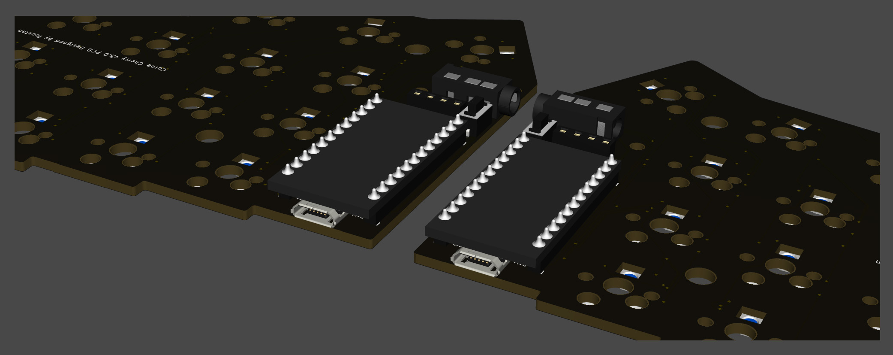
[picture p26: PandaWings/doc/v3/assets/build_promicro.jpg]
build_promicro


If you use [spring-loaded pin headers](https://shop.yushakobo.jp/collections/all-keyboard-parts/products/31),
you do not need to solder the back side.
Please refer to the [Helix Build Guide](
https://github.com/MakotoKurauchi/helix/blob/master/Doc/buildguide_en.md#pro-micro)
for details on how to use spring-loaded pin headers.

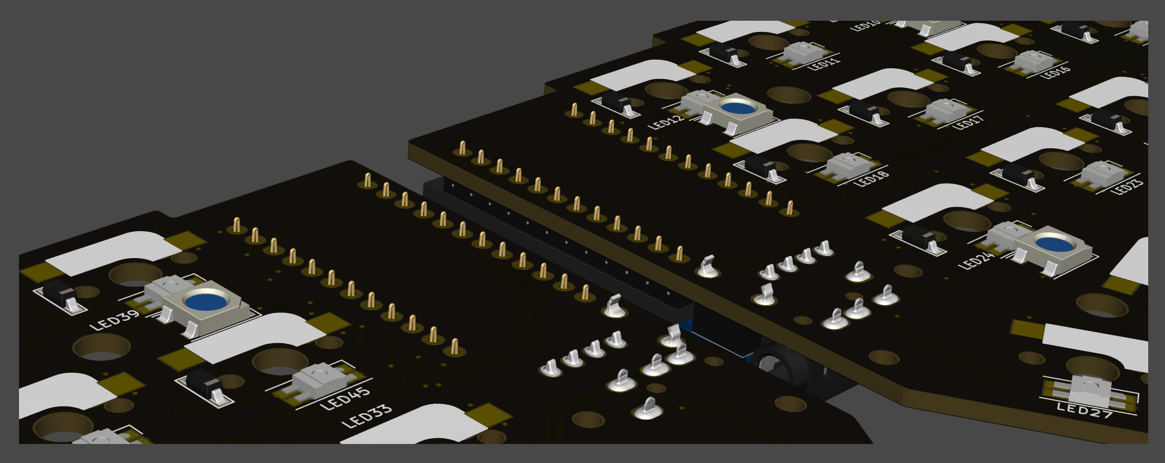
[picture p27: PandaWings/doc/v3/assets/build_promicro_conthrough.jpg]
build_promicro_conthrough


### OLED module

Insert the pin header into the socket first, then solder the OLED module
to the pin header.
Note: Solder one pin to OLED module, then reheat solder to confirm OLED module is level,
then solder remaining pins.

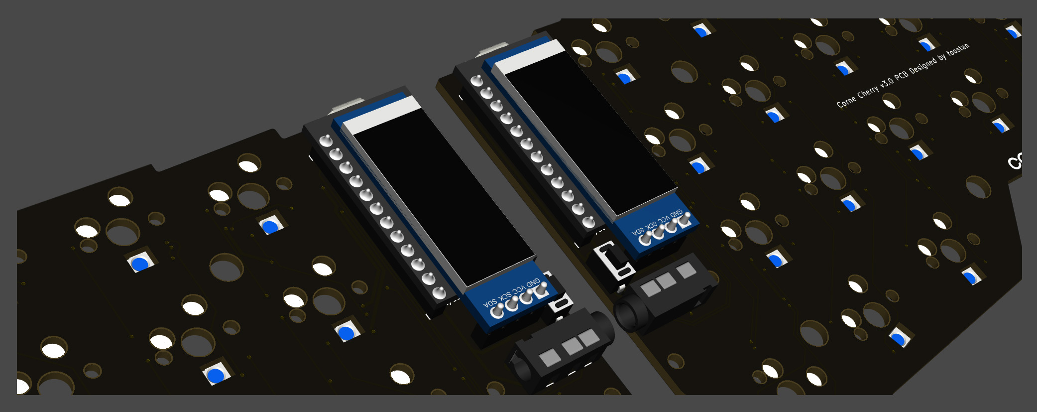
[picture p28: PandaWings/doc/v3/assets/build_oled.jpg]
build_oled


### Operation check

Now is a good time to test your keyboard to help isolate potential problems.

To check the operation, connect left and right sides with TRRS cable,
then connect left side to the computer with USB cable.
If it is done correctly so far, shorting a hotswap socket pad with tweezers will 
output out a keypress and it will be displayed on the OLED module.

### Switch Sockets

Solder hotswap sockets according to mark on PCB as shown below.
Refer to **TIPS: Tips for installing SMD parts** section above as similar soldering
procedure is followed. 

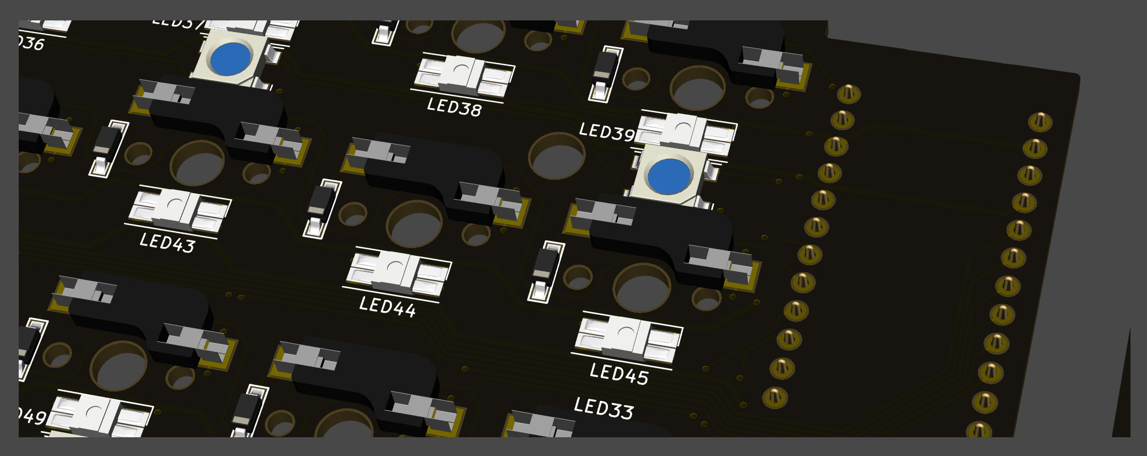
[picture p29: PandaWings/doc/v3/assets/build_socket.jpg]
build_socket


Switch Socket soldering is completed after 42 are installed on left and right.

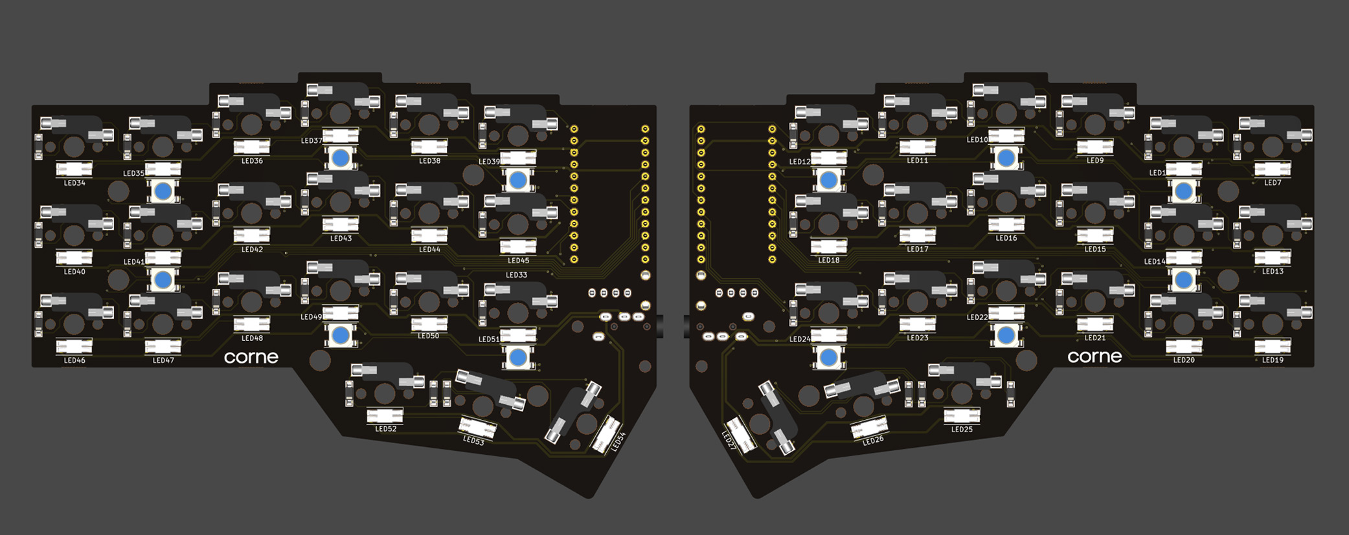
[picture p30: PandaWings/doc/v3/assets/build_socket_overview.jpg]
build_socket_overview


### OLED protective cover

Attach the OLED protective cover with M2 9mm spacers and M2 screws.

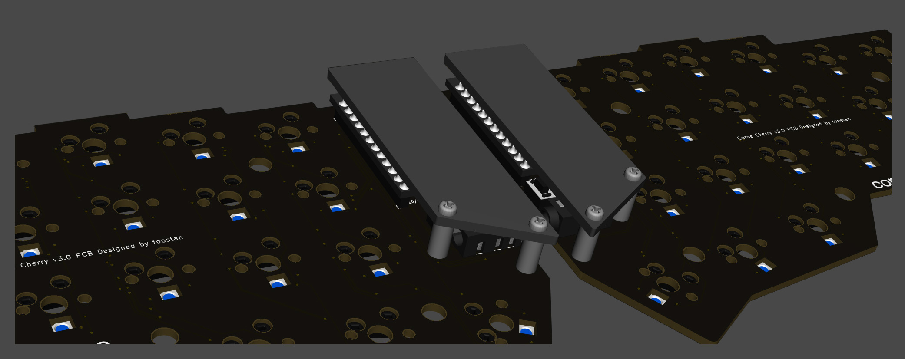
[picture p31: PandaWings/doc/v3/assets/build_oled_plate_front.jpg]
build_oled_plate_front

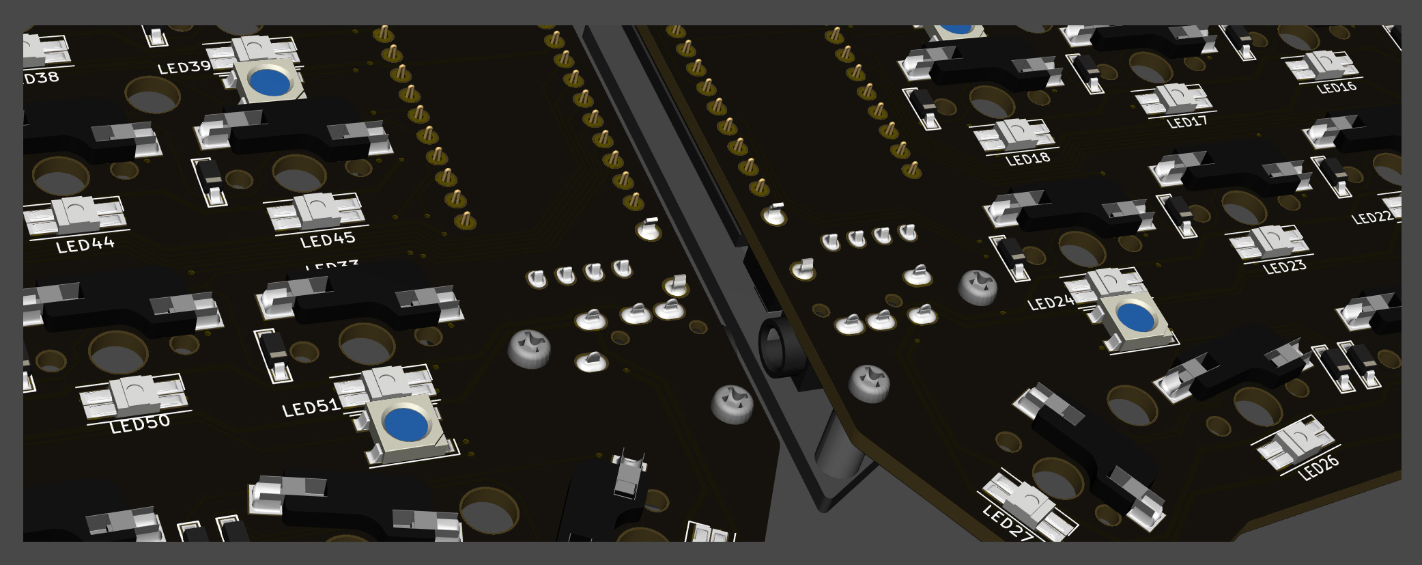
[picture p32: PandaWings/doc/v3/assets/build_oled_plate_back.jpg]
build_oled_plate_back


### Plates & Switches

Place a few key switches into the top plate, then line up and press into PCB socket.
If you attach all the key switches to the top plate first,
it will be more difficult to fit them in the PCB sockets all at once.
So it is recommended to do a few to begin with. 

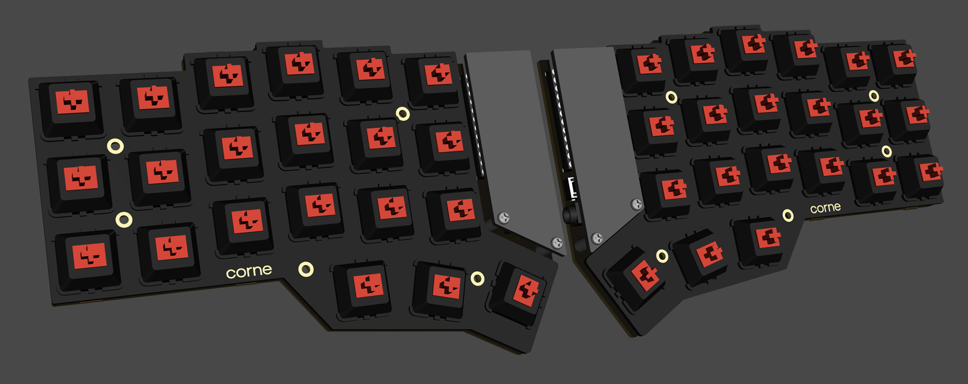
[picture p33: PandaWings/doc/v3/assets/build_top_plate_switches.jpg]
build_top_plate_switches


Install the M2 7.5mm spacer and M2 screws on the top plate.

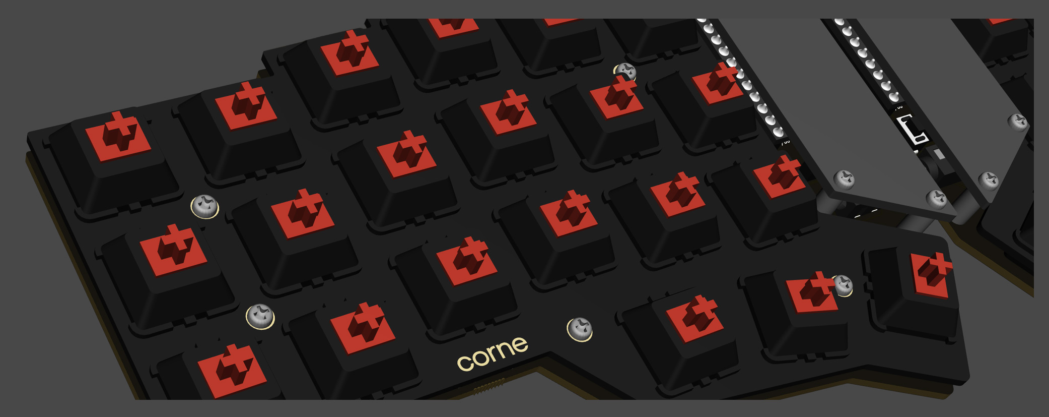
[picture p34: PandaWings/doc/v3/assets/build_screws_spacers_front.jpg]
build_screws_spacers_front


It is easy to screw the spacer in after inserting it into the hole from the back side.

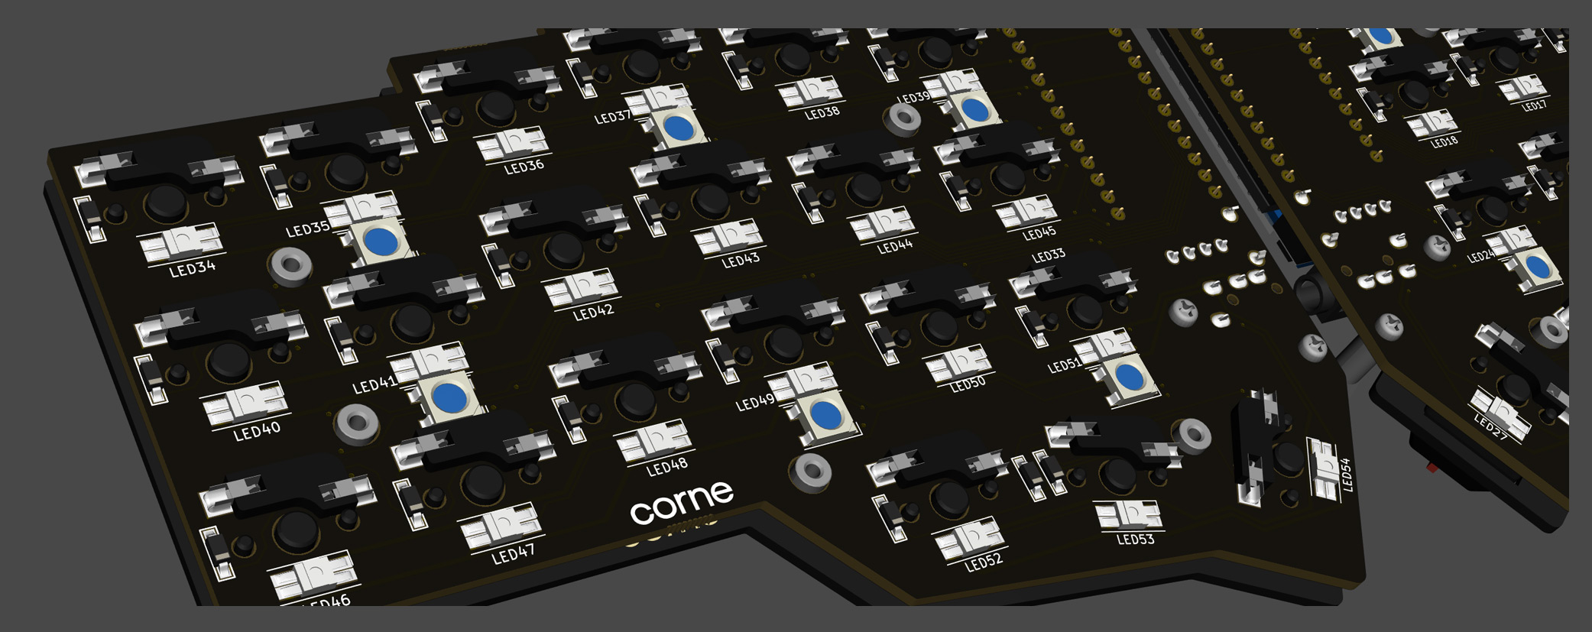
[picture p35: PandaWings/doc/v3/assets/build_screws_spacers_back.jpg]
build_screws_spacers_back


Attach the bottom plate with M2 screws.

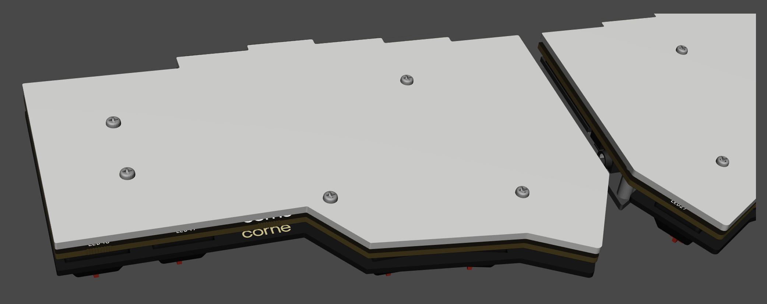
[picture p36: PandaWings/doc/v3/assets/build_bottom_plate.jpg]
build_bottom_plate


Install the rubber feet in the following positions.

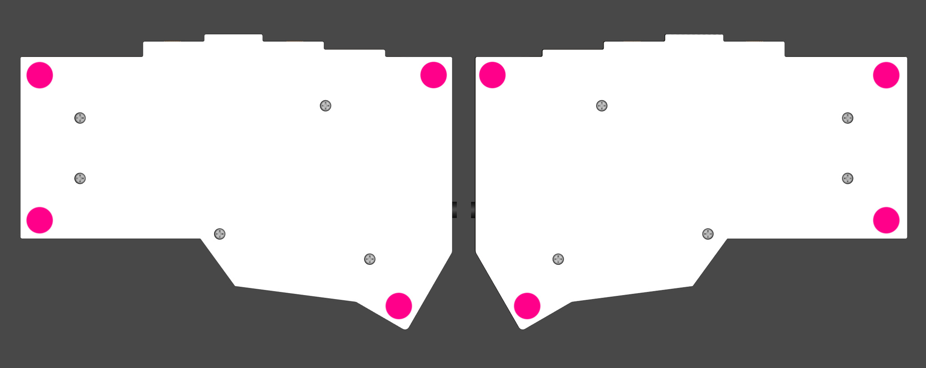
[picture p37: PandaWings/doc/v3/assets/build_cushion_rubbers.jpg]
build_cushion_rubbers


That's it!

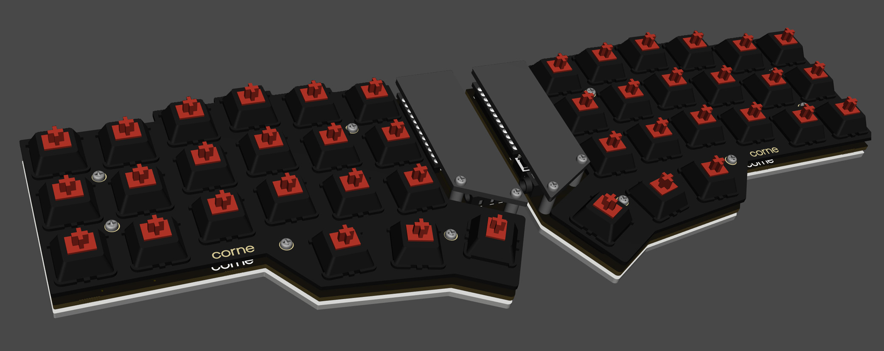
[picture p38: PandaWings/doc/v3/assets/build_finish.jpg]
build_finish


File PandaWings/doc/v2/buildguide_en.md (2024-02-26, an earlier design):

# Build Guide

This is the build guide for Corne Cherry v2.
[Click here for the Corne Cherry v3 build guide](
https://github.com/foostan/crkbd/blob/master/corne-cherry/doc/v3/buildguide_en.md).

## Parts

### Required

| Name | Count | Remarks |
|:-|:-|:-|
| PCB | 2 sheets | |
| Top plate | 2 sheets | |
| Bottom plate | 2 sheets | PCB type and acrylic type can be selected |
| ProMicro protective plate | 2 sheets | |
| ProMicro | 2 sheets | |
| TRRS jack | 2 | |
| Tact switch | 2 | |
| Diodes | 42 | Only chip parts |
| Kailh PCB Sockets | 42 | |
| Key switches | 42 | Only compatible with CherryMX |
| Keycaps | 42 pcs | 1u 40 pcs, 1.5u 2 pcs |
| OLED module | 2 sheets | |
| 4 pin headers | 2 | |
| 4 pin sockets | 2 | |
| Spacer M2 7.5mm | 10 pieces | |
| Spacer M2 9mm | 4 pieces | |
| Screw M2 4mm | 28 screws | |
| Cushion rubber | 8 pieces | |
| TRS (3-pole) cable | 1 | TRRS (4-pole) cable is also acceptable |
| Micro USB cable | 1 | |

### Optional

| Name | Count | Remarks |
|:-|:-|:-|
| SK6812MINI | 54 pcs | Upward mounting 42 pcs, Downward mounting 12 pcs |



## Advance preparation

If you build the firmware yourself,
it takes time to prepare the environment,
so it is recommended to start first. \
See <https://github.com/foostan/crkbd/blob/master/doc/firmware_en.md>
for more information.

## Implementation

The PCB is reversible, so first decide which one to use,
left or right.



### Diodes

Solder the diode of the chip part.
You can attach it to either side, but in this build guide,
we will attach it to the back side.
When using [Tilting / Tenting plate](
https://github.com/foostan/crkbd/blob/master/corne-cherry/doc/buildguide_tilting_tenting_plate_en.md),
be sure to attach it to the back side \_\_.

Since the chip parts are very small,
it is easier to work with tweezers and counter-acting tweezers.
**The diode is installed in a fixed direction **,
so if you arrange the diode in the same row and row as shown in the photo below,
it will proceed smoothly.



The orientation of the diode is as follows:
Install so that the "|||" mark on the chip part faces the "|" of the diode mark "|◁".



The trick is to attach the chip parts, but first, as a spare solder,
put the solder only on the right side of the pad.



Next, solder one leg of the diode so that the spare solder melts.
At this time, it is recommended to use reverse-action tweezers,
because you can hold the chip parts firmly without exerting force
and you can concentrate on alignment and soldering.
Also, if the soldering iron is too hot or the solder is touched too much,
the flux contained in the solder may evaporate and form a clean pile of solder,
but it can be repaired later,
so at this point you should only care about attaching parts.
It's okay.



It is okay if the diode does not float when viewed from the side
when one foot is attached.
If it floats, press the diode with tweezers or your fingers
and reheat the soldered part with a soldering iron to clean it.



Then solder the other one.
Be careful not to apply too much,
as a small amount of solder is sufficient.
If you apply too much, you can remove it with a blotting wire
or by scooping it with a soldering iron.

If the amount of solder on the preliminary solder side is small,
additional soldering is performed, and if it is a mountain,
apply flux from above and heat it to clean it.



### TRRS jack, reset switch

Solder the TRRS jack and reset switch to the surface of the PCB
as shown in the picture below.
In this build guide, the diode is attached to the back side,
so it is the opposite side.



### Jumpers and pin sockets for OLED modules

When using the OLED module, jumper as shown below.
Please note that **only the surface should be jumpered**.

Solder the pin socket to the same surface.



If the jumper doesn't work, the amount of solder is probably too low
or the flux in the solder has vaporized.
In that case, you can fix a jumper by using a large amount of solder
or applying a separate flux.

### ProMicro

Solder the pin header so that it fits into the white frame,
and then solder it with the back side of the Pro Micro facing up.




If you want to use spring-loaded pin headers,
please refer to the [Helix Build Guide](
https://github.com/MakotoKurauchi/helix/blob/master/Doc/buildguide_en.md#pro-micro).

### OLED module

Insert the pin header into the pin socket for OLED first,
and then solder the pin header and OLED module.
At this time, the OLED module is easy to float,
so be careful not to float it while pressing it with your finger.




### Operation check

It is recommended to check the operation when ProMicro and OLED module are attached
(it will be difficult to isolate the problem if you do it at the very end).

To check the operation, first insert the firmware for crkbd into ProMicro
by referring to the "Firmware" chapter below (be sure to insert it on both sides).

To check the operation,
connect the left hand side to the PC with MicroUSB,
and connect the left hand side and the right hand side with the TRS cable.
Since there may be defects such as jacks,
be sure to connect the left and right instead of one by one
before checking the operation.
If it is done correctly so far,
if you short the pad to attach the PCB socket with tweezers etc.,
the key pressed on the OLED module will be displayed.



### Kailh PCB Socket

Fill the pads on both sides of the back with solder.
It is difficult to add it later, so please add more in advance.



Insert the socket and attach it by melting the solder you have.
At this time, hold it down with tweezers or your fingers
so that the socket does not float.



Soldering is now complete.
If you want to add an LED as an option,
refer to the "LED" chapter below
(it can be attached even after installing the socket).



### Plates, switches

First, insert the switch into the top plate.
It's okay to do it later, but it's easier to put it in first,
because it's necessary to insert the switch from a little bit.



Finally, attach the spacers with screws so that the top plate, PCB,
and bottom plate are in that order,
and attach the cushion rubber to the four corners to complete the process.



## Firmware

Write the firmware to ProMicro by referring to the following. \
<https://github.com/foostan/crkbd/blob/master/doc/firmware_en.md>

## LED (optional)

I will install the SK6812 MINI.

The SK6812MINI is extremely heat sensitive and breaks easily.
We recommend using a soldering iron with a temperature control function
and working at a temperature of 220°C to 270°C.
Even if the temperature is adjusted,
it will be damaged if the iron is applied to the LED for a long time,
so try to solder as quickly as possible.
The LEDs are soldered four by four,
but it is recommended that you do not do four at a time,
but two at a time to prevent the LED temperature from rising,
as it will be less likely to break.

First, check the mounting position.

Solder 1 to 6 so that the back side (Undergrow) shines,
and 7 to 27 so that the front side (Backlight) shines.
Below is the position to install the LED.




Solder 1 to 6 so that the black part circled as shown below is on the bottom
and the silk mark indicated by the arrow is on the top.
Please note that the orientation changes between 1 ~ 3 and 4 ~ 5.



Solder 7 to 27 so that the largest pad circled
and the silk mark indicated by the arrow are adjacent to each other,
as shown below.



If everything can be soldered normally, it will shine as shown below.
If it shines only halfway, the LEDs are connected in numerical order,
so suspect that the LED that does not shine
or the LED in front of it is soldered incorrectly or that the LED is damaged.



That's all there is to it.



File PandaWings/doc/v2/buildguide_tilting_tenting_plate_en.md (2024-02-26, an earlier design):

# Build Guide Tilting / Tenting plate

## Parts

| Name | Count | Remarks |
|:-|:-|:-|
| Completed Corne Cherry | 1 set | Corne Chocolate / 3mm top plate is not supported |
| Middle plate 3mm | 2 sheets | |
| Bottom plate 3mm | 2 sheets | |
| Bolt M5 15mm ~ 50mm | 8 bolts | |
| Nut M5 | 16 pieces | |
| Screw M2 6mm | 10 screws | |
| Screw M2 4mm | 10 screws | |
| Spacer M2 3.5mm | 10 pieces | |
| Cushion rubber | 8 pieces | |

## Advance preparation

lrg_dsc05736

Remove the key switch from the finished Corne Cherry
to separate the body from the top plate.
No other parts are needed.

## Assembly

lrg_dsc05737
lrg_dsc05739

Check the required parts.
Check the dedicated middle plate and bottom plate, and bolts of various lengths.
In addition, use screws, nuts, spacers, etc. (see the parts section for details).

lrg_dsc05742

Secure the middle plate to the top plate with 6mm screws and 3.5mm spacers.

lrg_dsc05744
Secure the OLED display protection plate with 4mm screws.

lrg_dsc05745

Secure the body and bottom plate with 4mm screws.

lrg_dsc05747

Insert an acrylic spacer between the middle plate
and the bottom plate and attach the bolts.

lrg_dsc05748

It is recommended to temporarily assemble the bolts
and adjust the height before completely fixing them with nuts.
Temporary assembly can be done easily by passing only one nut through the bolt.

lrg_dsc05749
lrg_dsc05750

It is completed by firmly fixing it so that it is sandwiched between nuts.

lrg_dsc05761

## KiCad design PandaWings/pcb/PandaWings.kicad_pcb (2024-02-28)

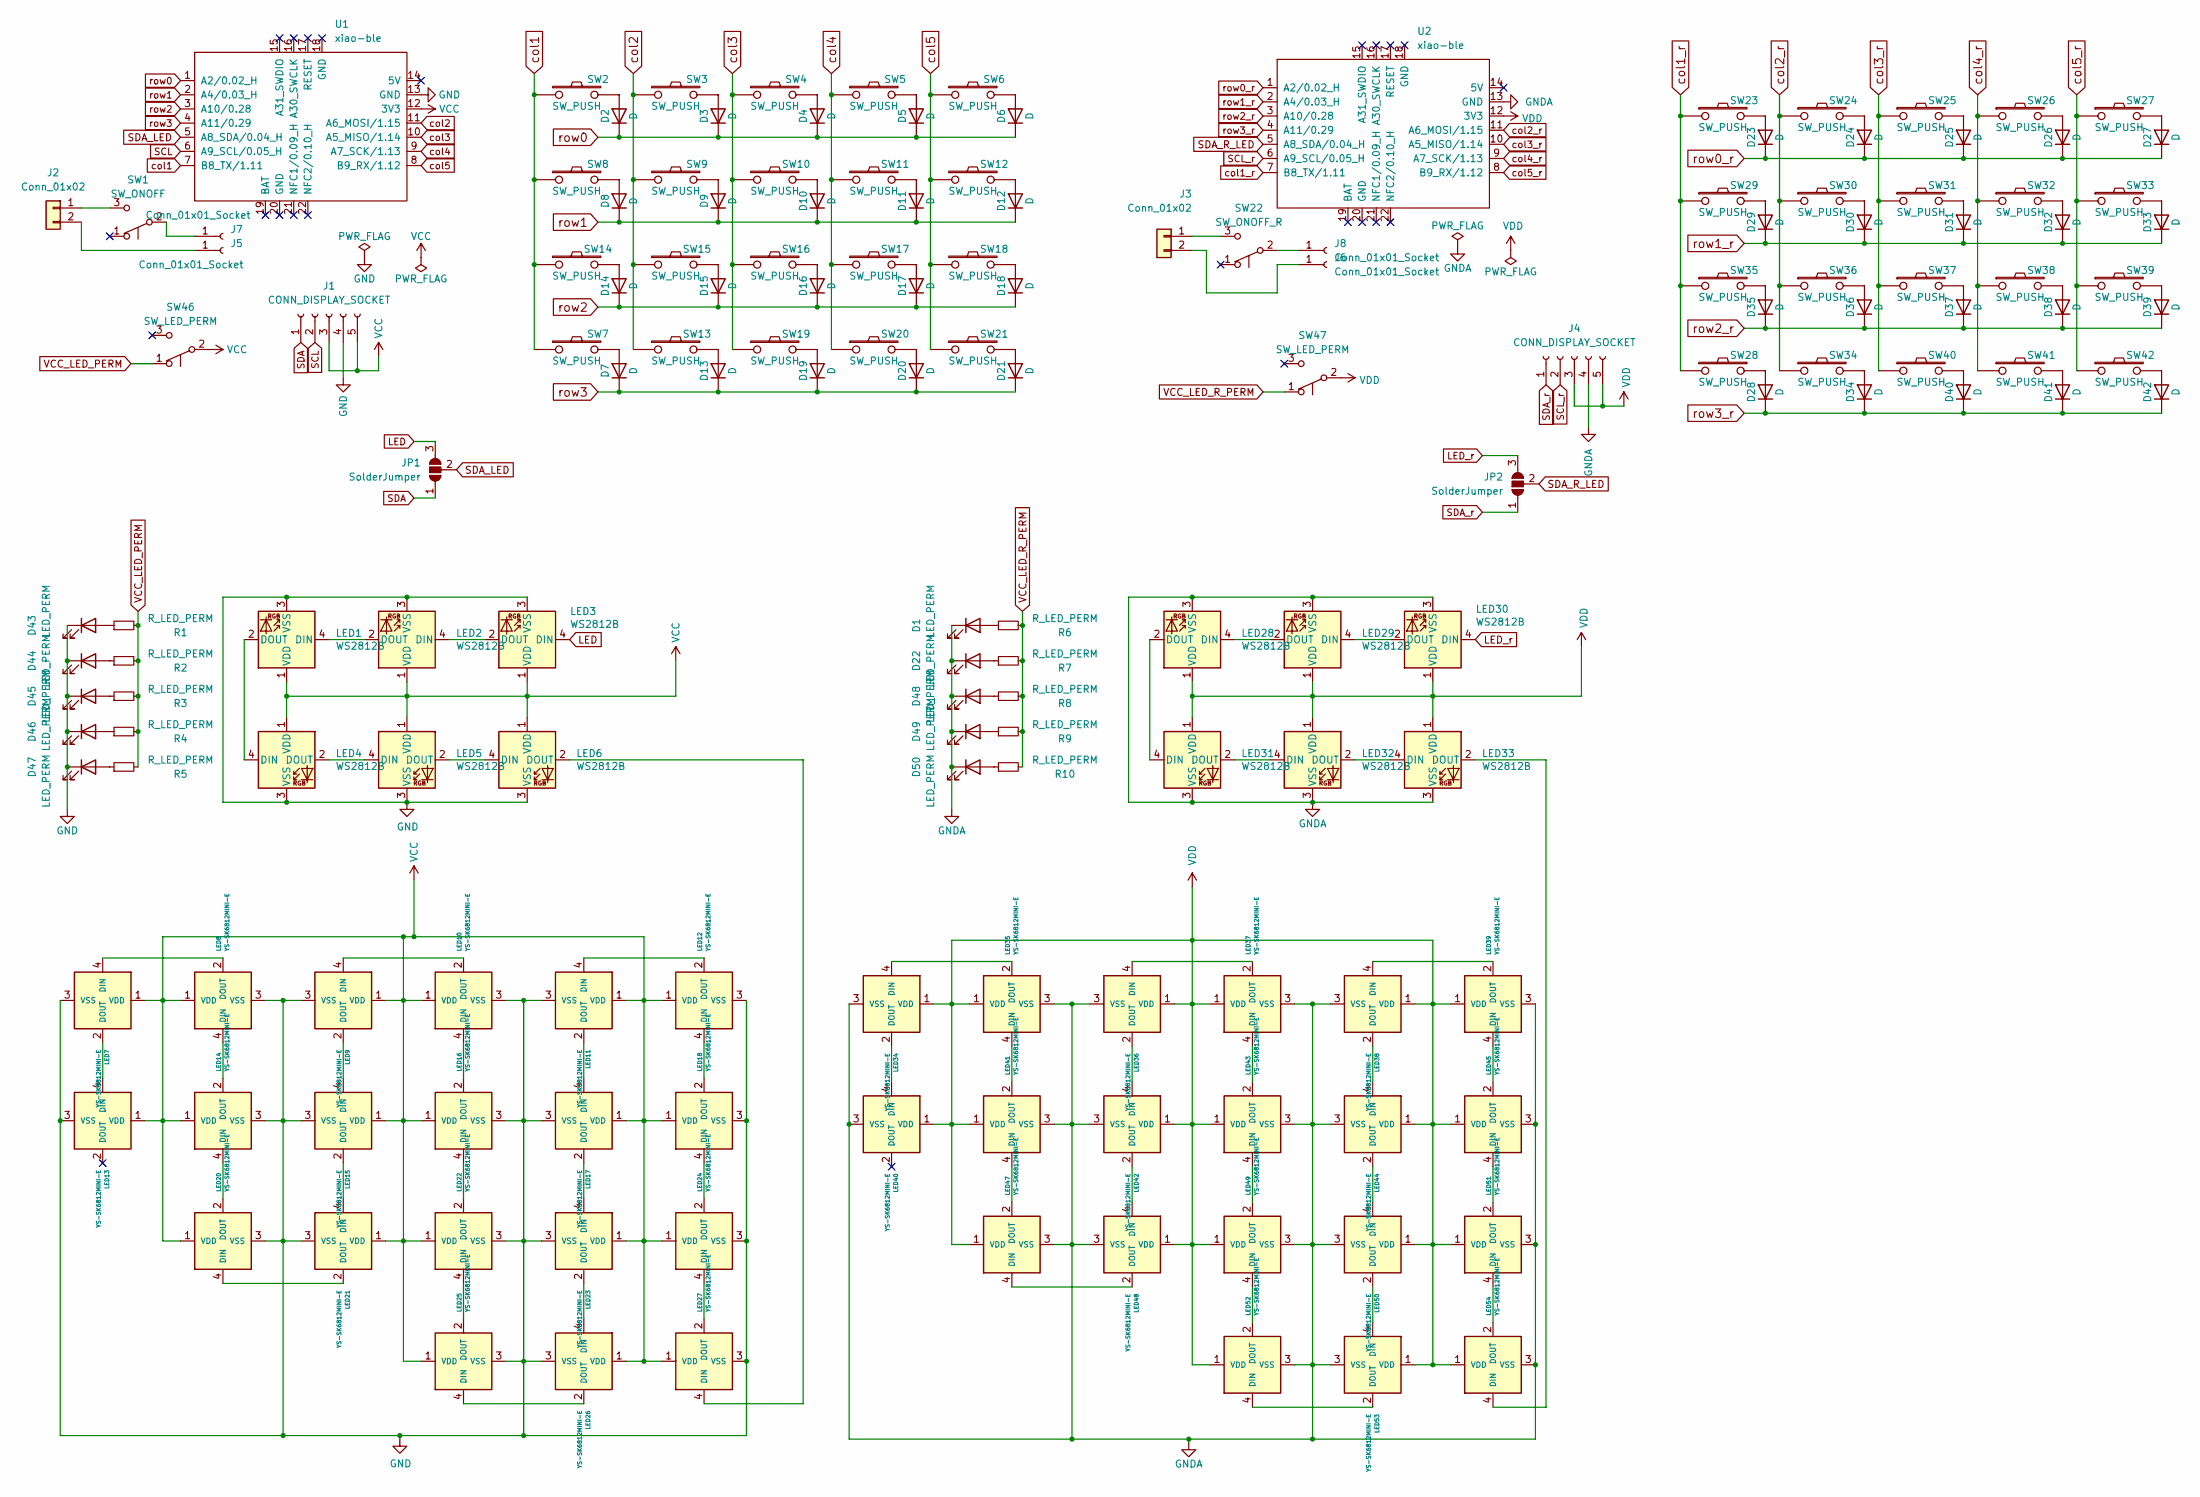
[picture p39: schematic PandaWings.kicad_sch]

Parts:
D1, D22, D43, D44, D45, D46, D47, D48, D49, D50: LED_PERM; LED_0603_1608Metric
D2, D3, D4, D5, D6, D7, D8, D9, D10, D11, D12, D13, D14, D15, D16, D17, D18, D19, D20, D21, D23, D24, D25, D26, D27, D28, D29, D30, D31, D32, D33, D34, D35, D36, D37, D38, D39, D40, D41, D42: D; D3_SMD_v2
J1, J4: CONN_DISPLAY_SOCKET; PinSocket_1x05_P2.54mm_Vertical
J2, J3: Conn_01x02; JST_PH_S2B-PH-K_1x02_P2.00mm_Horizontal
J5, J6, J7, J8: Conn_01x01_Socket; SolderJumper-2_P1.3mm_Bridged_RoundedPad1.0x1.5mm
JP1, JP2: SolderJumper; SolderJumper-3_P1.3mm_Open_Pad1.0x1.5mm_NumberLabels
LED1, LED2, LED3, LED4, LED5, LED6, LED28, LED29, LED30, LED31, LED32, LED33: WS2812B; LED_WS2812B_PLCC4_5.0x5.0mm_P3.2mm
LED7, LED8, LED9, LED10, LED11, LED12, LED13, LED14, LED15, LED16, LED17, LED18, LED20, LED21, LED22, LED23, LED24, LED25, LED26, LED27, LED34, LED35, LED36, LED37, LED38, LED39, LED40, LED41, LED42, LED43, LED44, LED45, LED47, LED48, LED49, LED50, LED51, LED52, LED53, LED54: YS-SK6812MINI-E
R1, R2, R3, R4, R5, R6, R7, R8, R9, R10: R_LED_PERM; R_0603_1608Metric
SW1: SW_ONOFF; SW_SPDT_PCM12
SW2, SW3, SW4, SW5, SW6, SW7, SW8, SW9, SW10, SW11, SW12, SW13, SW14, SW15, SW16, SW17, SW18, SW19, SW20, SW23, SW24, SW25, SW26, SW27, SW28, SW29, SW30, SW31, SW32, SW33, SW34, SW35, SW36, SW37, SW38, SW39, SW40, SW41: SW_PUSH; CherryMX_Hotswap
SW21, SW42: SW_PUSH; CherryMX_Hotswap_1.5u
SW22: SW_ONOFF_R; SW_SPDT_PCM12
SW46, SW47: SW_LED_PERM; SW_SPDT_PCM12
U1, U2: xiao-ble; XIAO-Generic-Thruhole-14P-2.54-21X17.8MM

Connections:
GND: D43.1 (K), D44.1 (K), D45.1 (K), D46.1 (K), D47.1 (K), J1.4, LED1.3 (VSS), LED2.3 (VSS), LED3.3 (VSS), LED4.3 (VSS), LED5.3 (VSS), LED6.3 (VSS), LED7.3 (VSS), LED8.3 (VSS), LED9.3 (VSS), LED10.3 (VSS), LED11.3 (VSS), LED12.3 (VSS), LED13.3 (VSS), LED14.3 (VSS), LED15.3 (VSS), LED16.3 (VSS), LED17.3 (VSS), LED18.3 (VSS), LED20.3 (VSS), LED21.3 (VSS), LED22.3 (VSS), LED23.3 (VSS), LED24.3 (VSS), LED25.3 (VSS), LED26.3 (VSS), LED27.3 (VSS), U1.13 (GND); also elsewhere on the board
GNDA: D1.1 (K), D22.1 (K), D48.1 (K), D49.1 (K), D50.1 (K), J4.4, LED28.3 (VSS), LED29.3 (VSS), LED30.3 (VSS), LED31.3 (VSS), LED32.3 (VSS), LED33.3 (VSS), LED34.3 (VSS), LED35.3 (VSS), LED36.3 (VSS), LED37.3 (VSS), LED38.3 (VSS), LED39.3 (VSS), LED40.3 (VSS), LED41.3 (VSS), LED42.3 (VSS), LED43.3 (VSS), LED44.3 (VSS), LED45.3 (VSS), LED47.3 (VSS), LED48.3 (VSS), LED49.3 (VSS), LED50.3 (VSS), LED51.3 (VSS), LED52.3 (VSS), LED53.3 (VSS), LED54.3 (VSS), U2.13 (GND); also elsewhere on the board
LED: JP1.3 (B), LED3.4 (DIN)
LED_r: JP2.3 (B), LED30.4 (DIN)
unnamed: D1.2 (A), R6.1
unnamed: D2.2 (A), SW2.2
unnamed: D3.2 (A), SW3.2
unnamed: D4.2 (A), SW4.2
unnamed: D5.2 (A), SW5.2
unnamed: D6.2 (A), SW6.2
unnamed: D7.2 (A), SW7.2
unnamed: D8.2 (A), SW8.2
unnamed: D9.2 (A), SW9.2
unnamed: D10.2 (A), SW10.2
unnamed: D11.2 (A), SW11.2
unnamed: D12.2 (A), SW12.2
unnamed: D13.2 (A), SW13.2
unnamed: D14.2 (A), SW14.2
unnamed: D15.2 (A), SW15.2
unnamed: D16.2 (A), SW16.2
unnamed: D17.2 (A), SW17.2
unnamed: D18.2 (A), SW18.2
unnamed: D19.2 (A), SW19.2
unnamed: D20.2 (A), SW20.2
unnamed: D21.2 (A), SW21.2
unnamed: D22.2 (A), R7.1
unnamed: D23.2 (A), SW23.2
unnamed: D24.2 (A), SW24.2
unnamed: D25.2 (A), SW25.2
unnamed: D26.2 (A), SW26.2
unnamed: D27.2 (A), SW27.2
unnamed: D28.2 (A), SW28.2
unnamed: D29.2 (A), SW29.2
unnamed: D30.2 (A), SW30.2
unnamed: D31.2 (A), SW31.2
unnamed: D32.2 (A), SW32.2
unnamed: D33.2 (A), SW33.2
unnamed: D34.2 (A), SW34.2
unnamed: D35.2 (A), SW35.2
unnamed: D36.2 (A), SW36.2
unnamed: D37.2 (A), SW37.2
unnamed: D38.2 (A), SW38.2
unnamed: D39.2 (A), SW39.2
unnamed: D40.2 (A), SW40.2
unnamed: D41.2 (A), SW41.2
unnamed: D42.2 (A), SW42.2
unnamed: D43.2 (A), R1.1
unnamed: D44.2 (A), R2.1
unnamed: D45.2 (A), R3.1
unnamed: D46.2 (A), R4.1
unnamed: D47.2 (A), R5.1
unnamed: D48.2 (A), R8.1
unnamed: D49.2 (A), R9.1
unnamed: D50.2 (A), R10.1
unnamed 54: J2.1, SW1.3 (C); also elsewhere on the board
unnamed: J2.2, J5.1
unnamed 56: J3.1, SW22.3 (C); also elsewhere on the board
unnamed: J3.2, J6.1
unnamed 58: J7.1, SW1.2 (B); also elsewhere on the board
unnamed 59: J8.1, SW22.2 (B); also elsewhere on the board
unnamed: LED1.4 (DIN), LED2.2 (DOUT)
unnamed: LED1.2 (DOUT), LED4.4 (DIN)
unnamed: LED2.4 (DIN), LED3.2 (DOUT)
unnamed: LED4.2 (DOUT), LED5.4 (DIN)
unnamed: LED5.2 (DOUT), LED6.4 (DIN)
unnamed: LED7.4 (DIN), LED8.2 (DOUT)
unnamed: LED10.4 (DIN), LED16.2 (DOUT)
unnamed: LED9.4 (DIN), LED10.2 (DOUT)
unnamed: LED11.4 (DIN), LED12.2 (DOUT)
unnamed: LED11.2 (DOUT), LED17.4 (DIN)
unnamed: LED12.4 (DIN), LED18.2 (DOUT)
unnamed: LED7.2 (DOUT), LED13.4 (DIN)
unnamed: LED14.4 (DIN), LED20.2 (DOUT)
unnamed: LED8.4 (DIN), LED14.2 (DOUT)
unnamed: LED9.2 (DOUT), LED15.4 (DIN)
unnamed: LED15.2 (DOUT), LED21.4 (DIN)
unnamed: LED16.4 (DIN), LED22.2 (DOUT)
unnamed: LED17.2 (DOUT), LED23.4 (DIN)
unnamed: LED18.4 (DIN), LED24.2 (DOUT)
unnamed: LED20.4 (DIN), LED21.2 (DOUT)
unnamed: LED22.4 (DIN), LED25.2 (DOUT)
unnamed: LED23.2 (DOUT), LED26.4 (DIN)
unnamed: LED24.4 (DIN), LED27.2 (DOUT)
unnamed: LED25.4 (DIN), LED26.2 (DOUT)
unnamed: LED6.2 (DOUT), LED27.4 (DIN)
unnamed: LED28.4 (DIN), LED29.2 (DOUT)
unnamed: LED28.2 (DOUT), LED31.4 (DIN)
unnamed: LED29.4 (DIN), LED30.2 (DOUT)
unnamed: LED31.2 (DOUT), LED32.4 (DIN)
unnamed: LED32.2 (DOUT), LED33.4 (DIN)
unnamed: LED33.2 (DOUT), LED54.4 (DIN)
unnamed: LED34.4 (DIN), LED35.2 (DOUT)
unnamed: LED34.2 (DOUT), LED40.4 (DIN)
unnamed: LED35.4 (DIN), LED41.2 (DOUT)
unnamed: LED36.4 (DIN), LED37.2 (DOUT)
unnamed: LED36.2 (DOUT), LED42.4 (DIN)
unnamed: LED37.4 (DIN), LED43.2 (DOUT)
unnamed: LED38.4 (DIN), LED39.2 (DOUT)
unnamed: LED38.2 (DOUT), LED44.4 (DIN)
unnamed: LED39.4 (DIN), LED45.2 (DOUT)
unnamed: LED41.4 (DIN), LED47.2 (DOUT)
unnamed: LED42.2 (DOUT), LED48.4 (DIN)
unnamed: LED43.4 (DIN), LED49.2 (DOUT)
unnamed: LED44.2 (DOUT), LED50.4 (DIN)
unnamed: LED45.4 (DIN), LED51.2 (DOUT)
unnamed: LED47.4 (DIN), LED48.2 (DOUT)
unnamed: LED49.4 (DIN), LED52.2 (DOUT)
unnamed: LED50.2 (DOUT), LED53.4 (DIN)
unnamed: LED51.4 (DIN), LED54.2 (DOUT)
unnamed: LED52.4 (DIN), LED53.2 (DOUT)
SCL: J1.2, U1.6 (A9_SCL/0.05_H); also elsewhere on the board
SCL_r: J4.2, U2.6 (A9_SCL/0.05_H); also elsewhere on the board
SDA: J1.1, JP1.1 (A)
SDA_LED: JP1.2 (C), U1.5 (A8_SDA/0.04_H); also elsewhere on the board
SDA_R_LED: JP2.2 (C), U2.5 (A8_SDA/0.04_H); also elsewhere on the board
SDA_r: J4.1, JP2.1 (A)
VCC: J1.3, J1.5, LED1.1 (VDD), LED2.1 (VDD), LED3.1 (VDD), LED4.1 (VDD), LED5.1 (VDD), LED6.1 (VDD), LED7.1 (VDD), LED8.1 (VDD), LED9.1 (VDD), LED10.1 (VDD), LED11.1 (VDD), LED12.1 (VDD), LED13.1 (VDD), LED14.1 (VDD), LED15.1 (VDD), LED16.1 (VDD), LED17.1 (VDD), LED18.1 (VDD), LED20.1 (VDD), LED21.1 (VDD), LED22.1 (VDD), LED23.1 (VDD), LED24.1 (VDD), LED25.1 (VDD), LED26.1 (VDD), LED27.1 (VDD), SW46.2 (B), U1.12 (3V3); also elsewhere on the board
VCC_LED_PERM: R1.2, R2.2, R3.2, R4.2, R5.2, SW46.1 (A); also elsewhere on the board
VCC_LED_R_PERM: R6.2, R7.2, R8.2, R9.2, R10.2, SW47.1 (A); also elsewhere on the board
VDD: J4.3, J4.5, LED28.1 (VDD), LED29.1 (VDD), LED30.1 (VDD), LED31.1 (VDD), LED32.1 (VDD), LED33.1 (VDD), LED34.1 (VDD), LED35.1 (VDD), LED36.1 (VDD), LED37.1 (VDD), LED38.1 (VDD), LED39.1 (VDD), LED40.1 (VDD), LED41.1 (VDD), LED42.1 (VDD), LED43.1 (VDD), LED44.1 (VDD), LED45.1 (VDD), LED47.1 (VDD), LED48.1 (VDD), LED49.1 (VDD), LED50.1 (VDD), LED51.1 (VDD), LED52.1 (VDD), LED53.1 (VDD), LED54.1 (VDD), SW47.2 (B), U2.12 (3V3); also elsewhere on the board
col1: SW2.1, SW7.1, SW8.1, SW14.1, U1.7 (B8_TX/1.11); also elsewhere on the board
col1_r: SW23.1, SW28.1, SW29.1, SW35.1, U2.7 (B8_TX/1.11); also elsewhere on the board
col2: SW3.1, SW9.1, SW13.1, SW15.1, U1.11 (A6_MOSI/1.15); also elsewhere on the board
col2_r: SW24.1, SW30.1, SW34.1, SW36.1, U2.11 (A6_MOSI/1.15); also elsewhere on the board
col3: SW4.1, SW10.1, SW16.1, SW19.1, U1.10 (A5_MISO/1.14); also elsewhere on the board
col3_r: SW25.1, SW31.1, SW37.1, SW40.1, U2.10 (A5_MISO/1.14); also elsewhere on the board
col4: SW5.1, SW11.1, SW17.1, SW20.1, U1.9 (A7_SCK/1.13); also elsewhere on the board
col4_r: SW26.1, SW32.1, SW38.1, SW41.1, U2.9 (A7_SCK/1.13); also elsewhere on the board
col5: SW6.1, SW12.1, SW18.1, SW21.1, U1.8 (B9_RX/1.12); also elsewhere on the board
col5_r: SW27.1, SW33.1, SW39.1, SW42.1, U2.8 (B9_RX/1.12); also elsewhere on the board
row0: D2.1 (K), D3.1 (K), D4.1 (K), D5.1 (K), D6.1 (K), U1.1 (A2/0.02_H); also elsewhere on the board
row0_r: D23.1 (K), D24.1 (K), D25.1 (K), D26.1 (K), D27.1 (K), U2.1 (A2/0.02_H); also elsewhere on the board
row1: D8.1 (K), D9.1 (K), D10.1 (K), D11.1 (K), D12.1 (K), U1.2 (A4/0.03_H); also elsewhere on the board
row1_r: D29.1 (K), D30.1 (K), D31.1 (K), D32.1 (K), D33.1 (K), U2.2 (A4/0.03_H); also elsewhere on the board
row2: D14.1 (K), D15.1 (K), D16.1 (K), D17.1 (K), D18.1 (K), U1.3 (A10/0.28); also elsewhere on the board
row2_r: D35.1 (K), D36.1 (K), D37.1 (K), D38.1 (K), D39.1 (K), U2.3 (A10/0.28); also elsewhere on the board
row3: D7.1 (K), D13.1 (K), D19.1 (K), D20.1 (K), D21.1 (K), U1.4 (A11/0.29); also elsewhere on the board
row3_r: D28.1 (K), D34.1 (K), D40.1 (K), D41.1 (K), D42.1 (K), U2.4 (A11/0.29); also elsewhere on the board

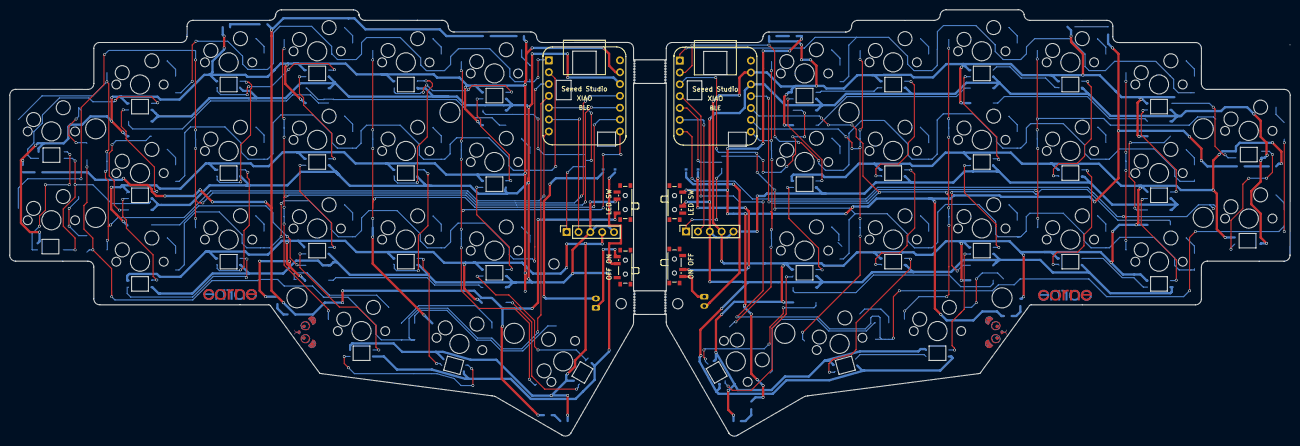
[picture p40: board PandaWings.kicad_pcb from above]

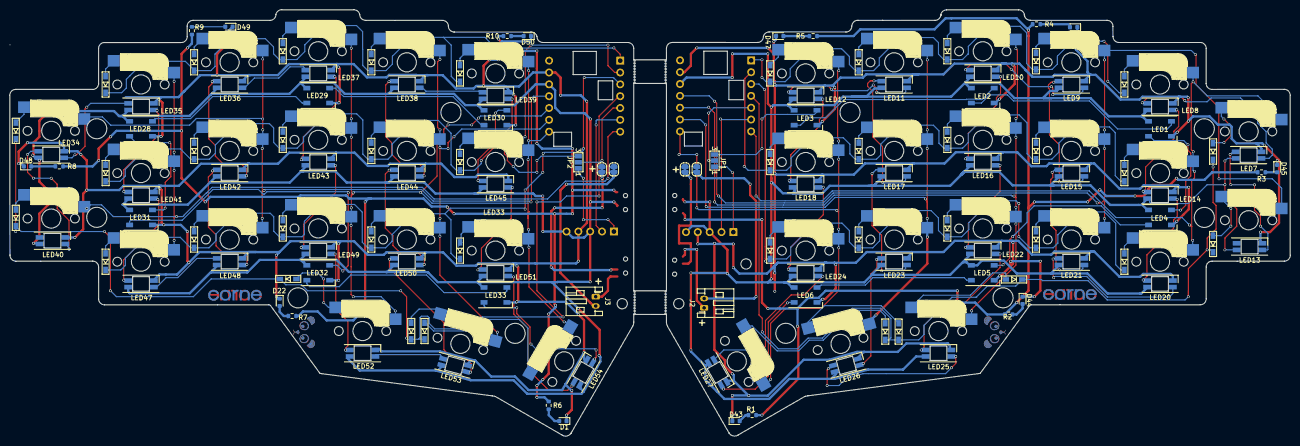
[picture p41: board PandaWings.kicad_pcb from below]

Board: 2 copper layers, 274.6 x 91.4 mm, 181 parts (122 on the bottom side), 138 nets.

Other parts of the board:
BLE: xiao-ble; XIAO-Generic-Thruhole-14P-2.54-21X17.8MM
BLE#2: xiao-ble; XIAO-Generic-Thruhole-14P-2.54-21X17.8MM
LED SW: SW_LED_PERM; SW_SPDT_PCM12
LED SW#2: SW_LED_PERM; SW_SPDT_PCM12
OFF ON: SW_ONOFF; SW_SPDT_PCM12
ON OFF: SW_ONOFF_R; SW_SPDT_PCM12
Ref**: Val**; M2_HOLE_v2
Ref**#2, Ref**#3, Ref**#4, Ref**#5, Ref**#6, Ref**#7, Ref**#8, Ref**#9, Ref**#10, Ref**#11, Ref**#12, Ref**#13: Val**; M2_HOLE_v2

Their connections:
GND: BLE#2.13 (GND); also elsewhere on the board
GNDA: BLE.13 (GND); also elsewhere on the board
unnamed 54: OFF ON.3 (C); also elsewhere on the board
unnamed 56: ON OFF.3 (C); also elsewhere on the board
unnamed 58: OFF ON.2 (B); also elsewhere on the board
unnamed 59: ON OFF.2 (B); also elsewhere on the board
SCL: BLE#2.6 (A9_SCL/0.05_H); also elsewhere on the board
SCL_r: BLE.6 (A9_SCL/0.05_H); also elsewhere on the board
SDA_LED: BLE#2.5 (A8_SDA/0.04_H); also elsewhere on the board
SDA_R_LED: BLE.5 (A8_SDA/0.04_H); also elsewhere on the board
VCC: BLE#2.12 (3V3), LED SW#2.2 (B); also elsewhere on the board
VCC_LED_PERM: LED SW#2.1 (A); also elsewhere on the board
VCC_LED_R_PERM: LED SW.1 (A); also elsewhere on the board
VDD: BLE.12 (3V3), LED SW.2 (B); also elsewhere on the board
col1: BLE#2.7 (B8_TX/1.11); also elsewhere on the board
col1_r: BLE.7 (B8_TX/1.11); also elsewhere on the board
col2: BLE#2.11 (A6_MOSI/1.15); also elsewhere on the board
col2_r: BLE.11 (A6_MOSI/1.15); also elsewhere on the board
col3: BLE#2.10 (A5_MISO/1.14); also elsewhere on the board
col3_r: BLE.10 (A5_MISO/1.14); also elsewhere on the board
col4: BLE#2.9 (A7_SCK/1.13); also elsewhere on the board
col4_r: BLE.9 (A7_SCK/1.13); also elsewhere on the board
col5: BLE#2.8 (B9_RX/1.12); also elsewhere on the board
col5_r: BLE.8 (B9_RX/1.12); also elsewhere on the board
row0: BLE#2.1 (A2/0.02_H); also elsewhere on the board
row0_r: BLE.1 (A2/0.02_H); also elsewhere on the board
row1: BLE#2.2 (A4/0.03_H); also elsewhere on the board
row1_r: BLE.2 (A4/0.03_H); also elsewhere on the board
row2: BLE#2.3 (A10/0.28); also elsewhere on the board
row2_r: BLE.3 (A10/0.28); also elsewhere on the board
row3: BLE#2.4 (A11/0.29); also elsewhere on the board
row3_r: BLE.4 (A11/0.29); also elsewhere on the board

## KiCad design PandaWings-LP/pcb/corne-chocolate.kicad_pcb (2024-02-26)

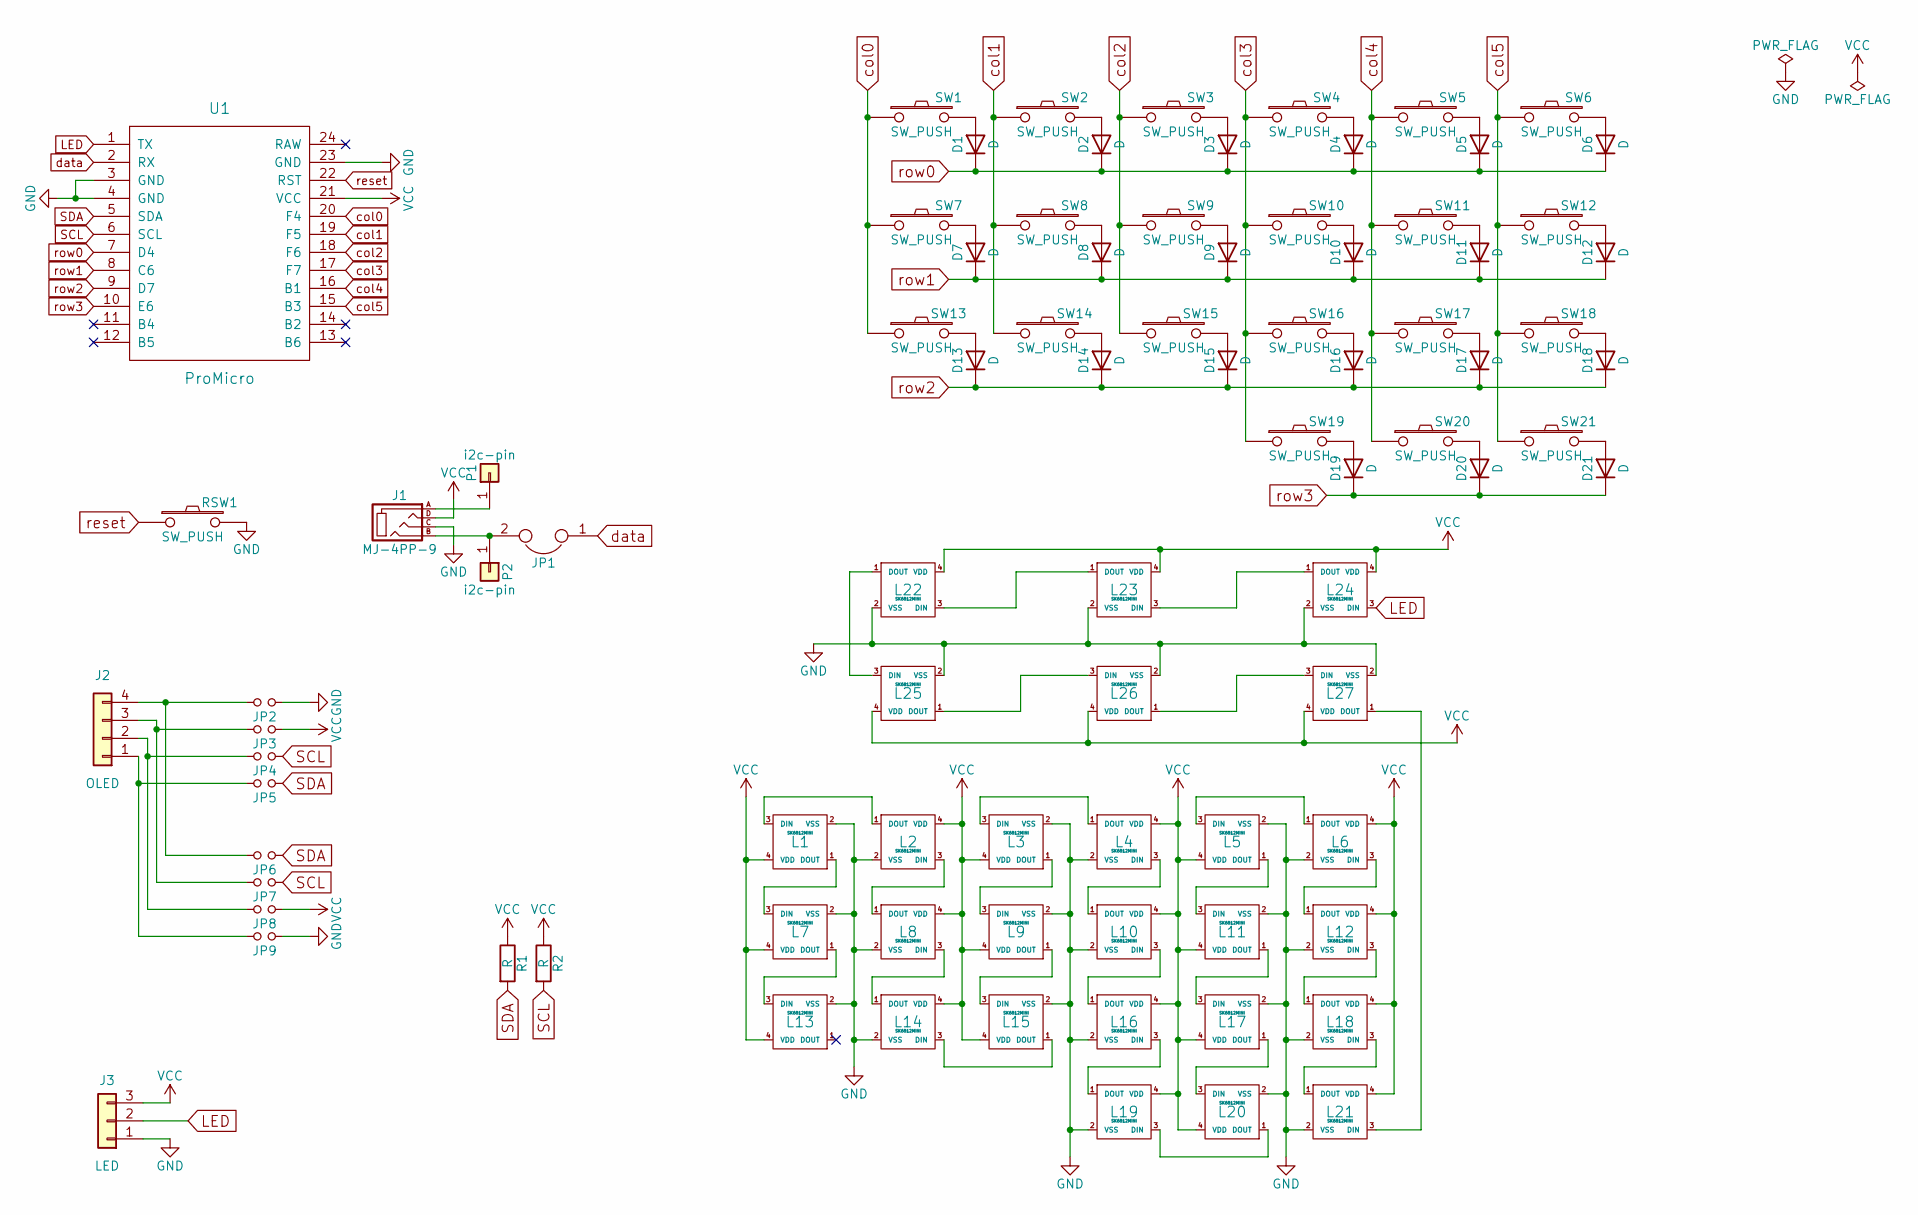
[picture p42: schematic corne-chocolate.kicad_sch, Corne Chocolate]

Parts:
D1, D2, D3, D4, D5, D6, D7, D8, D9, D10, D11, D12, D13, D14, D15, D16, D17, D18, D19, D20, D21: D; D3_TH_SMD
J1: MJ-4PP-9
J2: OLED
J3: LED; StripLED_rev
JP1: JPC2
JP2, JP3, JP4, JP5, JP6, JP7, JP8, JP9: Jumper
L1, L2, L3, L4, L5, L6, L7, L8, L9, L10, L11, L12, L13, L14, L15, L16, L17, L18, L19, L20, L21: SK6812MINI; SK6812MINI_rev
L22, L23, L24, L25, L26, L27: SK6812MINI; SK6812MINI_underglow
P1, P2: i2c-pin; 1pin_conn
R1, R2: R
RSW1: SW_PUSH; ResetSW
SW1, SW2, SW3, SW4, SW5, SW6, SW7, SW8, SW9, SW10, SW11, SW12, SW13, SW14, SW15, SW16, SW17, SW18, SW19, SW20: SW_PUSH; MX_ALPS_PG1350_noLed
SW21: SW_PUSH; MX_ALPS_PG1350_noLed_1.75u
U1: ProMicro; ProMicro_v2

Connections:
GND: J1.C, J3.1, JP2.1, JP9.1, L1.2 (VSS), L2.2 (VSS), L3.2 (VSS), L4.2 (VSS), L5.2 (VSS), L6.2 (VSS), L7.2 (VSS), L8.2 (VSS), L9.2 (VSS), L10.2 (VSS), L11.2 (VSS), L12.2 (VSS), L13.2 (VSS), L14.2 (VSS), L15.2 (VSS), L16.2 (VSS), L17.2 (VSS), L18.2 (VSS), L19.2 (VSS), L20.2 (VSS), L21.2 (VSS), L22.2 (VSS), L23.2 (VSS), L24.2 (VSS), L25.2 (VSS), L26.2 (VSS), L27.2 (VSS), RSW1.2, U1.3 (GND), U1.4 (GND), U1.23 (GND); also elsewhere on the board
LED: J3.2, L24.3 (DIN), U1.1 (TX)
unnamed: D1.2 (A), SW1.2
unnamed: D2.2 (A), SW2.2
unnamed: D3.2 (A), SW3.2
unnamed: D4.2 (A), SW4.2
unnamed: D5.2 (A), SW5.2
unnamed: D6.2 (A), SW6.2
unnamed: D7.2 (A), SW7.2
unnamed: D8.2 (A), SW8.2
unnamed: D9.2 (A), SW9.2
unnamed: D10.2 (A), SW10.2
unnamed: D11.2 (A), SW11.2
unnamed: D12.2 (A), SW12.2
unnamed: D13.2 (A), SW13.2
unnamed: D14.2 (A), SW14.2
unnamed: D15.2 (A), SW15.2
unnamed: D16.2 (A), SW16.2
unnamed: D17.2 (A), SW17.2
unnamed: D18.2 (A), SW18.2
unnamed: D19.2 (A), SW19.2
unnamed: D20.2 (A), SW20.2
unnamed: D21.2 (A), SW21.2
unnamed 23: J1.A, P1.1; also elsewhere on the board
unnamed 24: J1.B, JP1.2, P2.1; also elsewhere on the board
unnamed 25: J2.1, JP5.2, JP9.2; also elsewhere on the board
unnamed 26: J2.2, JP4.2, JP8.2; also elsewhere on the board
unnamed 27: J2.3, JP3.2, JP7.2; also elsewhere on the board
unnamed 28: J2.4, JP2.2, JP6.2; also elsewhere on the board
unnamed: L1.1 (DOUT), L7.3 (DIN)
unnamed: L1.3 (DIN), L2.1 (DOUT)
unnamed: L2.3 (DIN), L8.1 (DOUT)
unnamed: L3.1 (DOUT), L9.3 (DIN)
unnamed: L3.3 (DIN), L4.1 (DOUT)
unnamed: L5.3 (DIN), L6.1 (DOUT)
unnamed: L4.3 (DIN), L10.1 (DOUT)
unnamed: L10.3 (DIN), L16.1 (DOUT)
unnamed: L11.1 (DOUT), L17.3 (DIN)
unnamed: L5.1 (DOUT), L11.3 (DIN)
unnamed: L6.3 (DIN), L12.1 (DOUT)
unnamed: L12.3 (DIN), L18.1 (DOUT)
unnamed: L7.1 (DOUT), L13.3 (DIN)
unnamed: L8.3 (DIN), L14.1 (DOUT)
unnamed: L14.3 (DIN), L15.1 (DOUT)
unnamed: L9.1 (DOUT), L15.3 (DIN)
unnamed: L16.3 (DIN), L19.1 (DOUT)
unnamed: L17.1 (DOUT), L20.3 (DIN)
unnamed: L18.3 (DIN), L21.1 (DOUT)
unnamed: L19.3 (DIN), L20.1 (DOUT)
unnamed: L21.3 (DIN), L27.1 (DOUT)
unnamed: L22.1 (DOUT), L25.3 (DIN)
unnamed: L22.3 (DIN), L23.1 (DOUT)
unnamed: L23.3 (DIN), L24.1 (DOUT)
unnamed: L25.1 (DOUT), L26.3 (DIN)
unnamed: L26.1 (DOUT), L27.3 (DIN)
SCL: JP4.1, JP7.1, R2.2, U1.6 (SCL)
SDA: JP5.1, JP6.1, R1.2, U1.5 (SDA)
VCC: J1.D, J3.3, JP3.1, JP8.1, L1.4 (VDD), L2.4 (VDD), L3.4 (VDD), L4.4 (VDD), L5.4 (VDD), L6.4 (VDD), L7.4 (VDD), L8.4 (VDD), L9.4 (VDD), L10.4 (VDD), L11.4 (VDD), L12.4 (VDD), L13.4 (VDD), L14.4 (VDD), L15.4 (VDD), L16.4 (VDD), L17.4 (VDD), L18.4 (VDD), L19.4 (VDD), L20.4 (VDD), L21.4 (VDD), L22.4 (VDD), L23.4 (VDD), L24.4 (VDD), L25.4 (VDD), L26.4 (VDD), L27.4 (VDD), R1.1, R2.1, U1.21 (VCC); also elsewhere on the board
col0: SW1.1, SW7.1, SW13.1, U1.20 (F4)
col1: SW2.1, SW8.1, SW14.1, U1.19 (F5)
col2: SW3.1, SW9.1, SW15.1, U1.18 (F6)
col3: SW4.1, SW10.1, SW16.1, SW19.1, U1.17 (F7)
col4: SW5.1, SW11.1, SW17.1, SW20.1, U1.16 (B1)
col5: SW6.1, SW12.1, SW18.1, SW21.1, U1.15 (B3)
data: JP1.1, U1.2 (RX); also elsewhere on the board
reset: RSW1.1, U1.22 (RST)
row0: D1.1 (K), D2.1 (K), D3.1 (K), D4.1 (K), D5.1 (K), D6.1 (K), U1.7 (D4)
row1: D7.1 (K), D8.1 (K), D9.1 (K), D10.1 (K), D11.1 (K), D12.1 (K), U1.8 (C6)
row2: D13.1 (K), D14.1 (K), D15.1 (K), D16.1 (K), D17.1 (K), D18.1 (K), U1.9 (D7)
row3: D19.1 (K), D20.1 (K), D21.1 (K), U1.10 (E6)

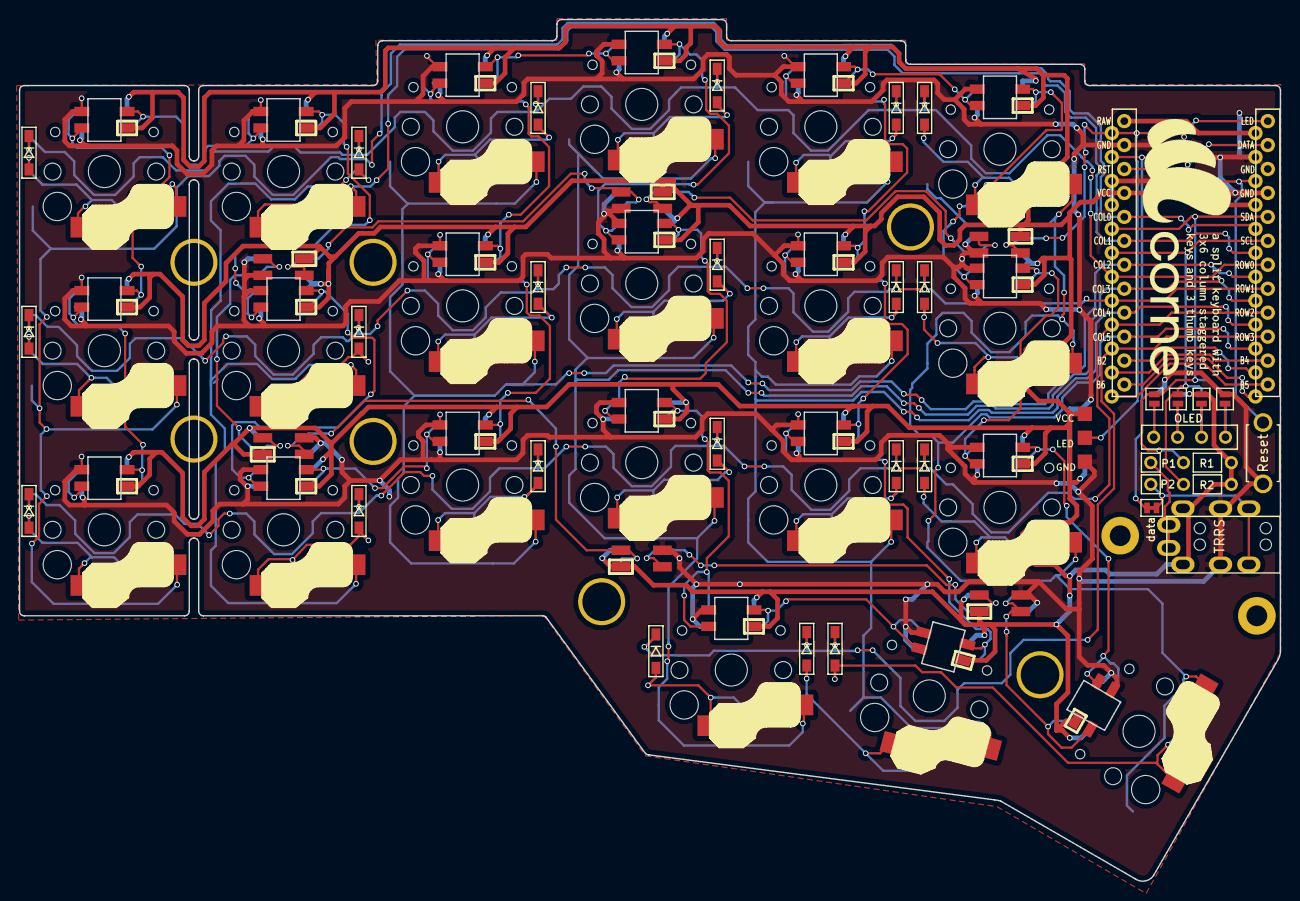
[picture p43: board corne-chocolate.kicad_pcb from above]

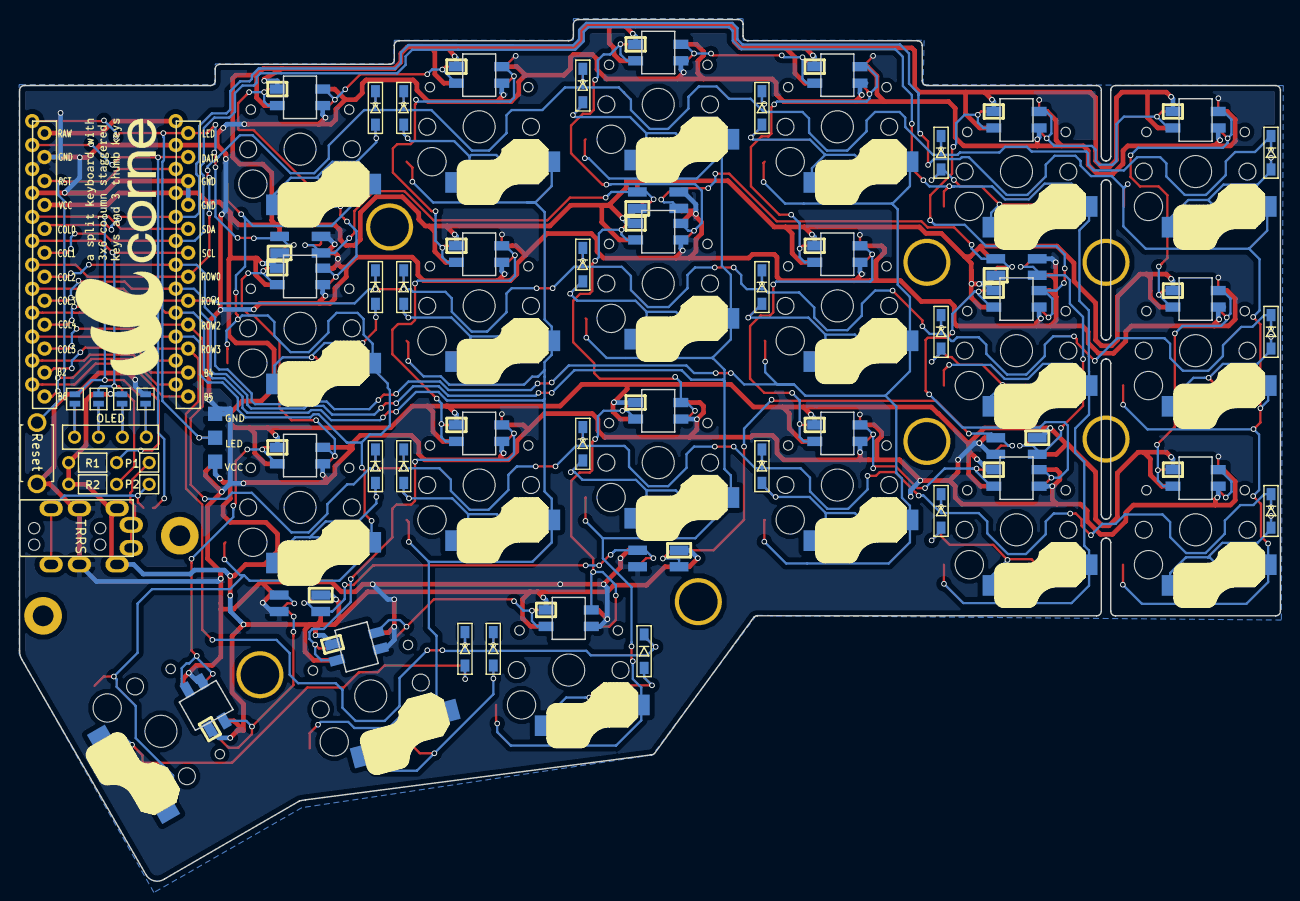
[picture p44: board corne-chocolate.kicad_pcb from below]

Board: 2 copper layers, 133.8 x 91.4 mm, 87 parts (4 on the bottom side), 70 nets.

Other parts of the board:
OLED: OLED
TRRS: MJ-4PP-9
data: JPC2

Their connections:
GND: TRRS.C; also elsewhere on the board
unnamed 23: TRRS.A; also elsewhere on the board
unnamed 24: TRRS.B, data.2; also elsewhere on the board
unnamed 25: OLED.1; also elsewhere on the board
unnamed 26: OLED.2; also elsewhere on the board
unnamed 27: OLED.3; also elsewhere on the board
unnamed 28: OLED.4; also elsewhere on the board
VCC: TRRS.D; also elsewhere on the board
data: data.1; also elsewhere on the board

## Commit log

2024-01-09 corne-cherry.kicad_sch: changed the components in the circuit diagram to make the corne fit the seeed xiao ble.
    [corne-cherry.kicad_pcb, corne-cherry.kicad_sch]
2024-02-11 finished track routing.
    [corne-cherry.kicad_pcb, corne-cherry.kicad_sch]
2024-02-12 corne-cherry.kicad_pcb: fixed some DRCs and rerouted some tracks.
    [corne-cherry.kicad_pcb]
2024-02-26 removed corne-classic and corne-light, renamed corne-cherry to PandaWings and corne-chocolate to PandaWings-LP
    [corne-cherry.kicad_pcb, corne-cherry.kicad_sch, corne-chocolate.kicad_pcb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]
2024-02-26 renamed project files for PandaWings.
    [PandaWings.kicad_pcb, PandaWings.kicad_sch]
2024-02-26 removed corne cases.
    [corne-bottom-plate.kicad_pcb, corne-top-alps-plate.kicad_pcb, corne-top-plate.kicad_pcb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]
2024-02-28 PandaWings: added revision text on schematic and pcb.
    [PandaWings.kicad_pcb, PandaWings.kicad_sch]
2024-03-01 added case/PandaWings.scad, firstly with case for the dongle.
    [PandaWings.scad]
2024-03-02 added vektor files for pcb.
2024-03-04 added helping sketches for the case design.
2024-03-04 added vektor geometries for case construction.
2024-03-04 PandaWings.scad: added model for switch plate.
    [PandaWings.scad]
2024-03-05 added vector ressources for the case.
2024-03-05 moved case vectors into case folder.
2024-03-05 added STL for switch plates with M3 screws.
    [PandaWings_SwitchPlates_M3.stl]
2024-03-05 restructured svgs for the case.
2024-03-05 PandaWings.scad: fixed faulty svg paths due to renaming.
    [PandaWings.scad]
2024-03-06 PandaWings.scad: added first sample for the case.
    [PandaWings.scad]
2024-03-07 PandaWings.scad: added surface for pcb to sit on.
    [PandaWings.scad]
2024-03-07 PandaWings.scad: added tenting holes.
    [PandaWings.scad]
2024-03-09 fixed position of the cutouts and added version with pcb for orientation.
2024-03-09 PandaWings.scad: fixed postition of the standoffs.
    [PandaWings.scad]
2024-03-09 PandaWings_SwitchPlates_M3.stl: fixed mounting diameter.
    [PandaWings_SwitchPlates_M3.stl]
2024-03-09 added case stl and fixed naming.
    [PandaWings_case_M3.stl, PandaWings_switch_plate_M3.stl]
2024-03-09 PandaWings_SwitchPlates_M3.stl: fixed mounting positions and added battery slot.
    [PandaWings.scad]
2024-03-10 PandaWings.scad: added mounting option for later wrist rest.
    [PandaWings.scad, PandaWings_case_M3.stl]
2024-03-14 added vector for
    wrist rest without case.
2024-03-26 PandaWings.scad: added caps for the tenting screws.
    [PandaWings.scad]
2024-03-26 PandaWings.scad: moved all components to be generated individually.
    [PandaWings.scad]
2024-03-26 added PandaWings tenting caps.
    [PandaWings_tenting_caps_M4.stl]
2024-03-28 added initial version for PandaWings Keycaps.
    [PandaWings-keycaps.scad]
2024-03-29 added code for all the different keycaps for PandaWings.
    [PandaWings-keycaps.scad]
2024-05-13 Keycaps: fixed travel height blocker, added stl with all caps.
    [PandaWings-keycaps.scad]
2024-05-13 Keycaps: added individual stl files for the different keys.
    [PandaWings-keycaps-mxsilver-alphanum-0-10x.stl, PandaWings-keycaps-mxsilver-alphanum-1-12x.stl, PandaWings-keycaps-mxsilver-alphanum-2-12x.stl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]
2024-05-15 Keycaps: added caps for glorious panda switches.
    [PandaWings-keycaps-glorioiuspanda-alphanum-0-10x.stl, PandaWings-keycaps-glorioiuspanda-alphanum-1-12x.stl, PandaWings-keycaps-glorioiuspanda-alphanum-2-12x.st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]
2024-08-13 PandaWings.scad: added tenting sockets to mount the keyboard with tripod helpers to a table.
    [PandaWings.scad]
2024-08-13 updated stl files according to changes in PandaWings.scad.
    [PandaWings_case_M3.stl, PandaWings_case_full_set.stl, PandaWings_dongle_case.stl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]
2024-12-21 case: added tenting option.
    [PandaWings.scad, PandaWings_case_full_set.stl, PandaWings_tenting_mounting_wood_screws.stl]
2024-12-21 keycaps: renamed variables.
    [PandaWings-keycaps.scad]
2024-12-21 pcb: updated version.
2024-12-21 keycaps: trying to fix pressing stop.
    [PandaWings-keycaps.scad]
2024-12-21 des: updated to latest commit.
2024-12-21 keycaps: added travel_stop to keys caps.
    [PandaWings-keycaps.scad]
2024-12-21 keycaps: fixed broken supports.
    [PandaWings-keycaps.scad]
2024-12-23 keycaps: changed the stem diameter to 5.7mm for the glorious switches.
2024-12-23 keycaps: changed the keycaps to an universal model with travel stop rings.
    [PandaWings-keycaps-alphanum-0-10x.stl, PandaWings-keycaps-alphanum-1-12x.stl, PandaWings-keycaps-alphanum-2-12x.stl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]
2024-12-26 keycaps: updated stl models.
    [PandaWings-keycaps-alphanum-0-10x.stl, PandaWings-keycaps-alphanum-1-12x.stl, PandaWings-keycaps-alphanum-2-12x.stl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]
2024-12-27 keycaps: removed travelstop due to incompatibility issues.
    [PandaWings-keycaps-gloriouspanda-travel-stop.stl, PandaWings-keycaps-mxsilver-travel-stop.stl]
2024-12-30 keycaps: updated stls.
    [PandaWings-keycaps-alphanum-0-10x.stl, PandaWings-keycaps-alphanum-1-12x.stl, PandaWings-keycaps-alphanum-2-12x.stl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]
